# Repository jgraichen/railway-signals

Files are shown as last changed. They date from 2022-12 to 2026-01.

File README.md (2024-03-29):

# German model railway signals

<em lang="en">This repository contains 3d models, parts, and electronic components and boards to build german railway signals for H0 model railroading.</em>

## Signalkomponenten

- [Masten, Körbe, Zubehör](freecad/KS/Masten/README.md)
- [KS-Signalschirme](freecad/KS/Signalschirme/README.md)
  - [PCB für Hauptsignale](kicad/Hauptsignal/README.md)
  - [PCB für Mehrabschnittssignale](kicad/Mehrabschnittssignal/README.md)
  - [PCB für Vorsignale](kicad/Vorsignal/README.md)
- [Zusatzsignale](freecad/KS/Zusatzsignale/README.md)
  - [PCB für Zusatzsignale](kicad/Zusatzsignal/README.md)

## Zubehör

### Signal-Treiberplatinen

- [Adapterplatine für MGP Signaldekoder](kicad/extra/ws2811-adapter/README.md)
- [LED Treiberboard für ein wechselbares Lichtsperrsignal](kicad/extra/ws2811-driver-6ls/README.md)
- [LED Treiberboard für zwei wechselbare Lichtsperrsignale](kicad/extra/ws2811-driver-9ls/README.md)
- [12 LED Treiberboard (1 Signal)](kicad/extra/ws2811-driver-12/README.md)
- [24 LED Treiberboard (2 Signale)](kicad/extra/ws2811-driver-24/README.md)
- [Wattenscheider Schacht für LED Treiberboards](freecad/watti-signal-mount/README.md)

## License

See individual components. Otherwise, all components and parts are licensed under a [Creative Commons Attribution-ShareAlike 4.0 International License](http://creativecommons.org/licenses/by-sa/4.0/).

(http://creativecommons.org/licenses/by-sa/4.0/)

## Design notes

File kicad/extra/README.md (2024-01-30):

# Extra components

## WS2811 Adapter Board

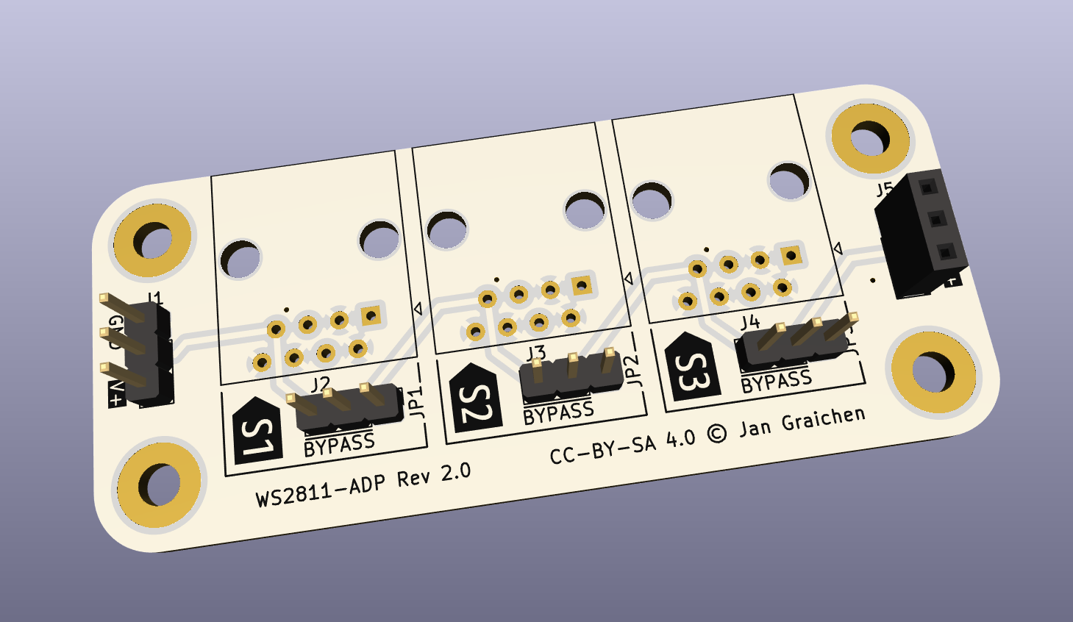
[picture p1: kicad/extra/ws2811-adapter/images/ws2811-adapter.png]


An adapter boards to connect MGP signal decoders with driver boards via RJ45 cables, for longer distances and easier cabling.

Supports bypassing ports and looping back the digital signal to organize and optimize LED ordering. See the [board README](ws2811-adapter/README.md) for more details.

## WS2811 Driver 12 (1 Signal)

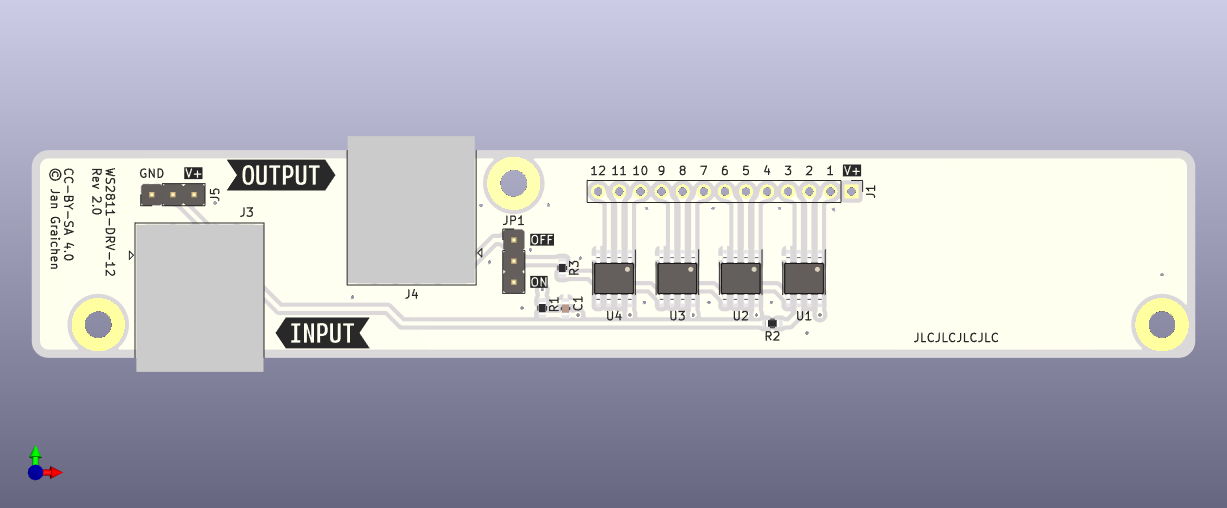
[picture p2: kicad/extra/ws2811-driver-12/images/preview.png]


[LED driver board providing 12 LEDs](ws2811-driver-12/), intended for up to one fully equipped German KS signal. Can be mounted in a [Wattenscheider Schacht](../../freecad/watti-signal-mount/).

## WS2811 Driver 24 (2 Signals)

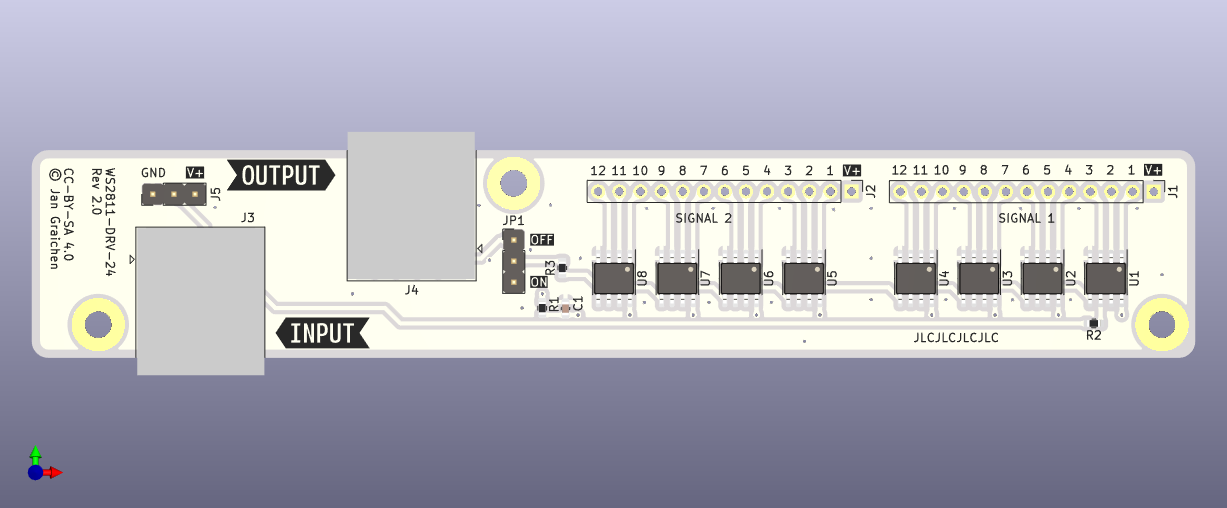
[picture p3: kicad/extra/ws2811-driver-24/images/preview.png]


A [24 LED driver board](ws2811-driver-24/) for up to two fully equipped German KS signal, usually mounted on a signal gantry. Can be mounted in a [Wattenscheider Schacht](../../freecad/watti-signal-mount/).

## WS2811 Driver 6LS (1 LS)

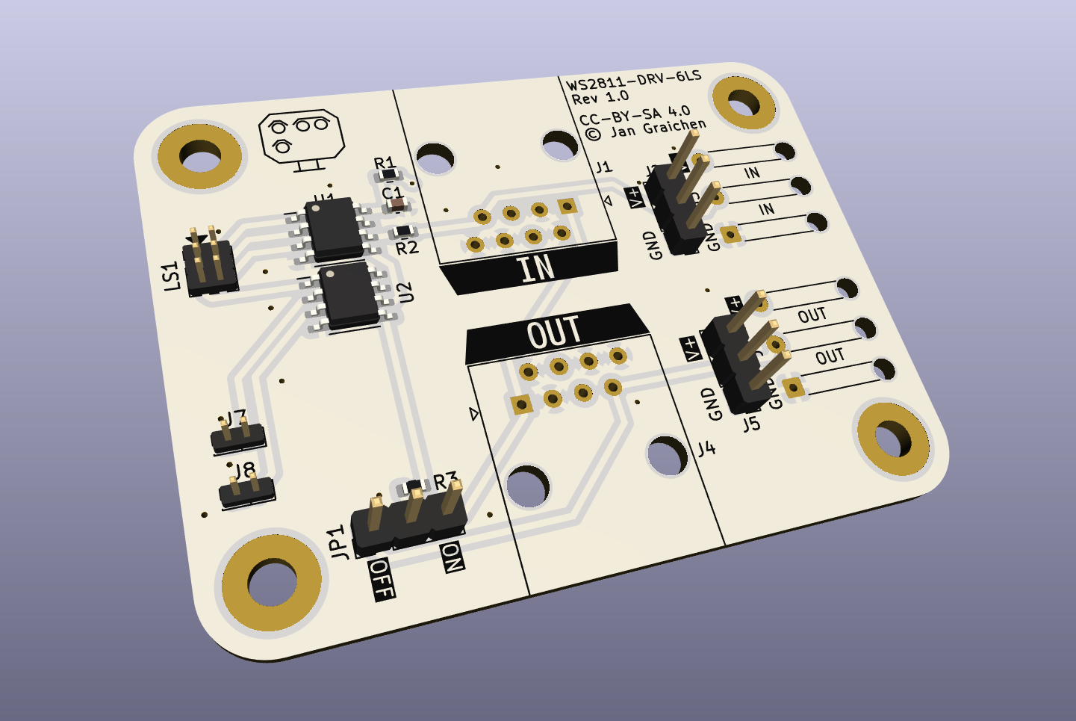
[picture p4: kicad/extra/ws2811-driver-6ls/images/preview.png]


This [driver board](ws2811-driver-6ls/) offers one tiny 2x3p 1 mm pitch connector for light shunting signals. The board can be mounted below the track, with the signal being mounted and connected through a 5 mm brass pole.

## WS2811 Driver 9LS (2 LS)

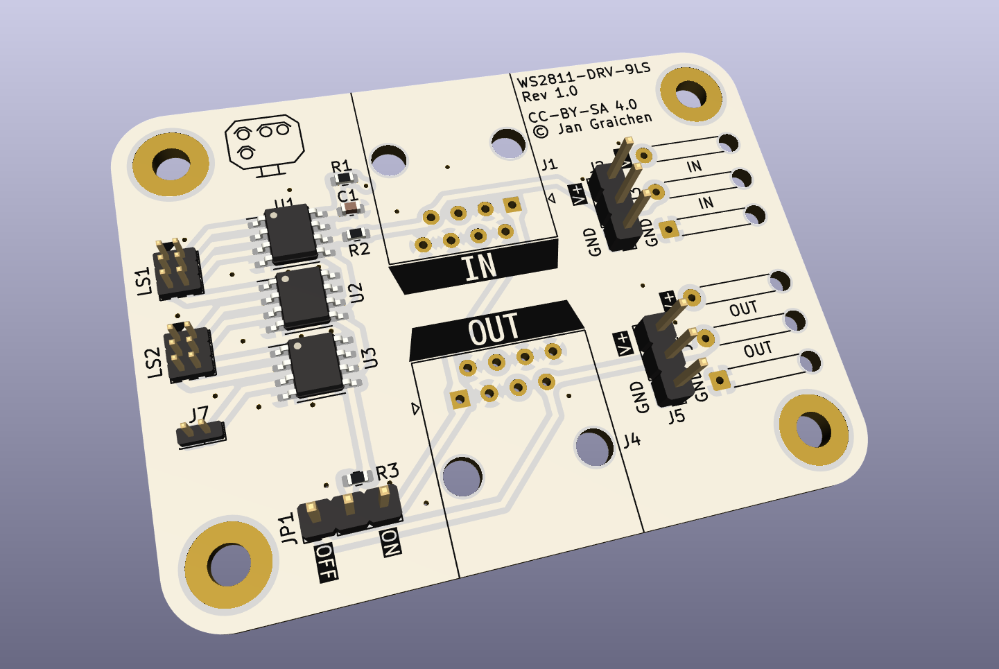
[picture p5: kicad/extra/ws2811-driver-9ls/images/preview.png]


This [driver board](ws2811-driver-9ls/) offers two tiny 2x3p 1 mm pitch connectors for light shunting signals. The board can be mounted below the track, with the signal being mounted and connected through a 5 mm brass pole.

## License

See individual components. Otherwise, all components and parts are licensed under a [Creative Commons Attribution-ShareAlike 4.0 International License](http://creativecommons.org/licenses/by-sa/4.0/).

(http://creativecommons.org/licenses/by-sa/4.0/)

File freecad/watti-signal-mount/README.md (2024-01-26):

# Wattenscheider signal mounts

With M3 screw mounts for [WS8211 LED driver boards](../../kicad/extra/).

## With latch

Signal mount has a 1 mm latch on top to stop the module from falling through.

<table>
  <tbody>
    <tr>
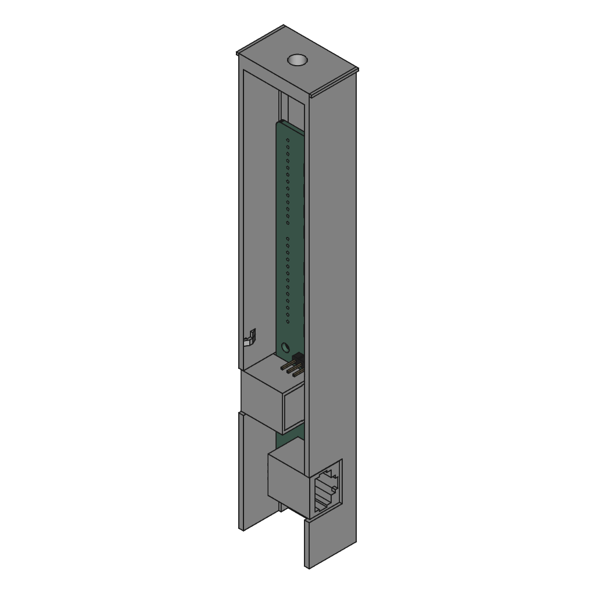
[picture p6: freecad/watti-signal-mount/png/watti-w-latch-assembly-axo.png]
      <td width="50%"></td>
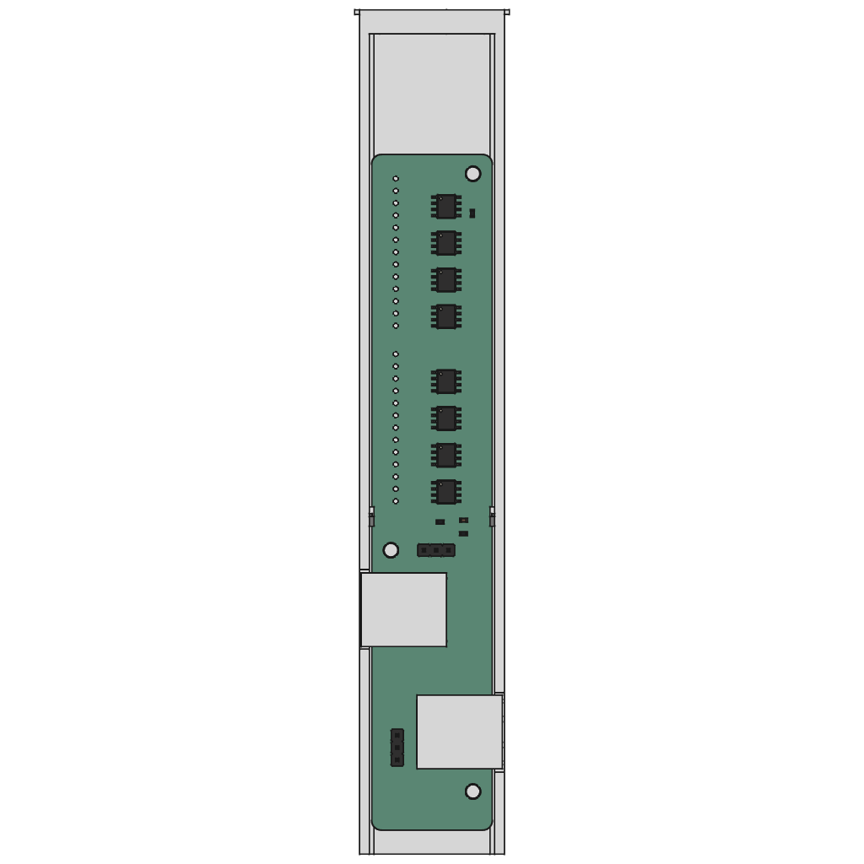
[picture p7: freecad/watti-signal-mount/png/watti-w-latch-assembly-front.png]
      <td width="50%"></td>
    </tr>
  </tbody>
</table>

* [STL model file](export/watti-w-latch-assembly.stl)
* [STEP model file](export/watti-w-latch-assembly.step)

## Without latch

<table>
  <tbody>
    <tr>
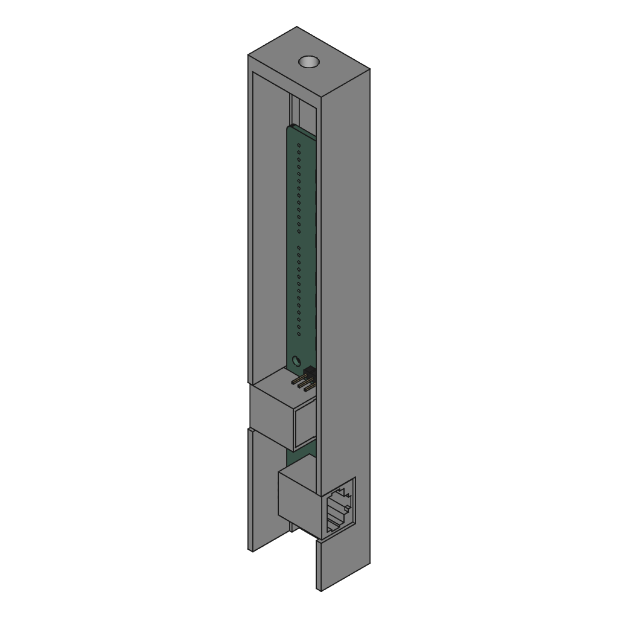
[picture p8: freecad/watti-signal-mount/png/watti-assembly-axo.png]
      <td width="50%"></td>
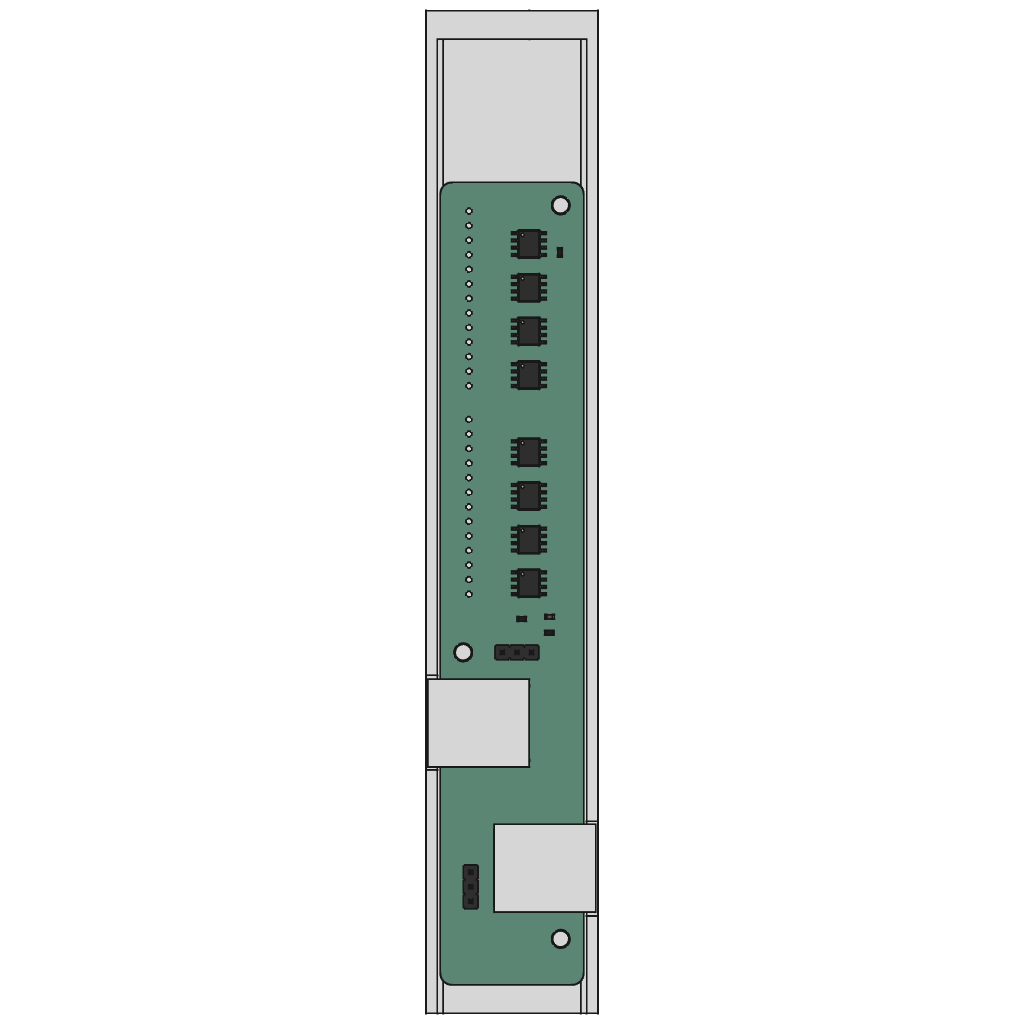
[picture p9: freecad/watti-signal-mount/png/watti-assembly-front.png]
      <td width="50%"></td>
    </tr>
  </tbody>
</table>

* [STL model file](export/watti-assembly.stl)
* [STEP model file](export/watti-assembly.step)

## License

This work is licensed under a
[Creative Commons Attribution-ShareAlike 4.0 International License](http://creativecommons.org/licenses/by-sa/4.0/).

(http://creativecommons.org/licenses/by-sa/4.0/)

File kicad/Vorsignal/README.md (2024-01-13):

# Vorsignal

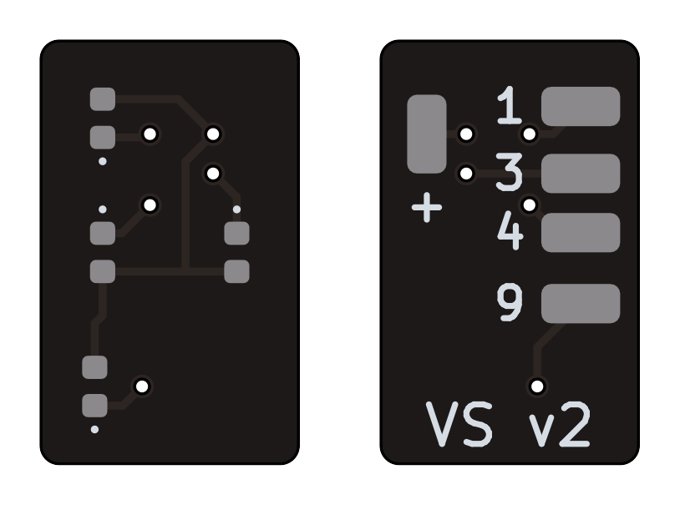
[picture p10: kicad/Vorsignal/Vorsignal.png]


Geeignet für KS-Vorsignale.

## Anschlussbelegung

| Schema | Pin-Belegung |
| --- | --- |
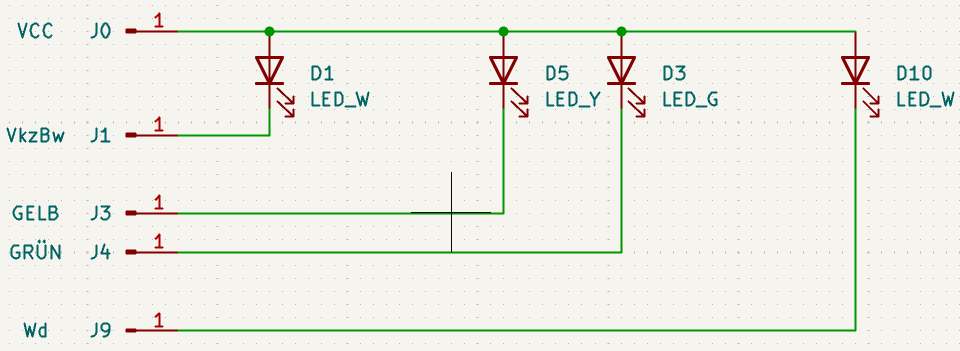
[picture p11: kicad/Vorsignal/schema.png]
Schema
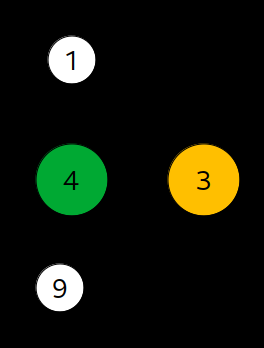
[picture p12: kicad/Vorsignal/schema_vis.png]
Pin-Belegung
|  |  |

| Referenz | Pin | LED | Funktion |
| --- | --- | --- | --- |
| J0 | + | | Stromversorgung (+) |
| J1 | 1 | Kaltweiß | Verkürzter Bremswegabstand |
| J3 | 3 | Gelb | Ks2 (Halt erwarten) |
| J4 | 4 | Grün | Ks1 (Fahrt erwarten) |
| J9 | 9 | Kaltweiß | Wiederholer |

## License

This work is licensed under a
[Creative Commons Attribution-ShareAlike 4.0 International License](http://creativecommons.org/licenses/by-sa/4.0/).

(http://creativecommons.org/licenses/by-sa/4.0/)

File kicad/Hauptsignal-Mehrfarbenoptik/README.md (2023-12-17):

# Hauptsignal mit mehrfarbiger Optik MSOv1

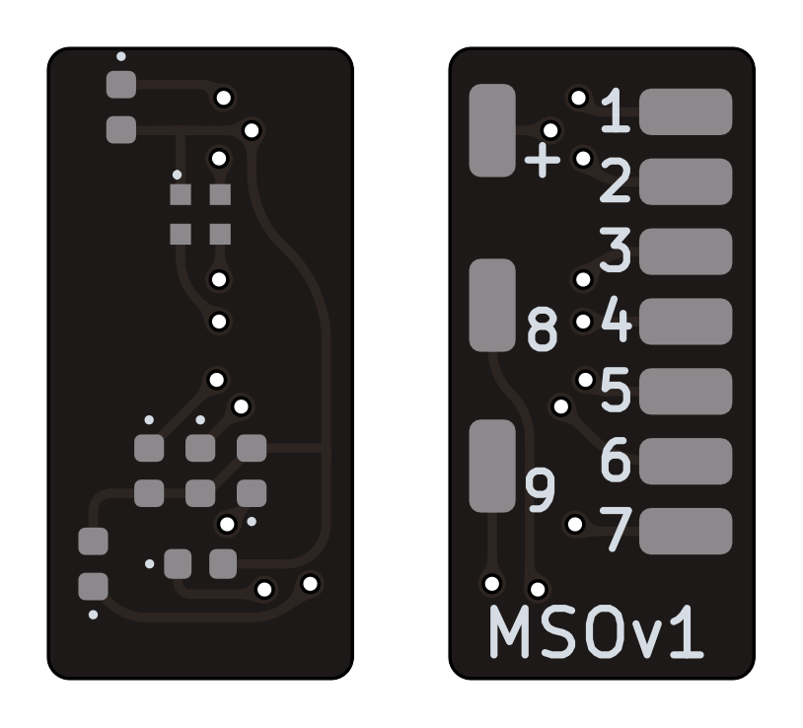
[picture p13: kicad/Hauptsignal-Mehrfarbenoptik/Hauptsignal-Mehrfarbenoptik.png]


Geeignet für KS-Hauptsignale und Mehrabschnitssignale mit mehrfarbiger Optik über eine ARGB-LED.

Pin 1 muss die gemeinsame Anode der RGB LED sein, die anderen Pins können je nach Bedarf Rot, Grün, oder Blau sein. Das ermöglicht auch den Einsatz auch von zum Beispiel ARGB und ARBG LEDs.

## Anschlussbelegung

| Schema | Pin-Belegung |
| --- | --- |
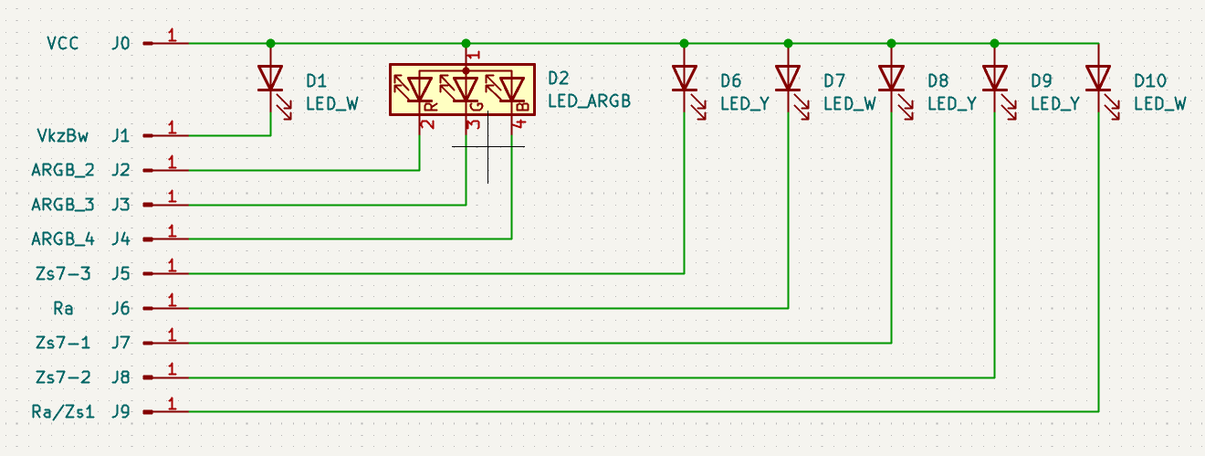
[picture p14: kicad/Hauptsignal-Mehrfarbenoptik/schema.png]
Schema
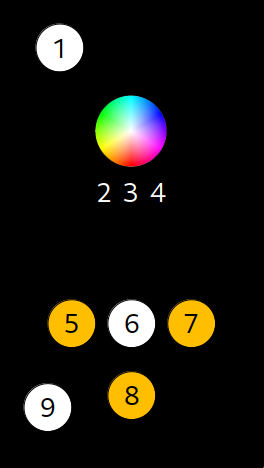
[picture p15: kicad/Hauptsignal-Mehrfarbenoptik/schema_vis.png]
Pin-Belegung
|  |  |

| Referenz | Pin | LED | Funktion |
| --- | --- | --- | --- |
| J0 | + | | Stromversorgung (+) |
| J1 | 1 | Kaltweiß | Zusatzlicht (oben) |
| J2 | 2 | ARGB_2 | RGB Led Pin 2 |
| J3 | 3 | ARGB_3 | RGB Led Pin 3 |
| J4 | 4 | ARGB_4 | RGB Led Pin 4 |
| J5 | 5 | Gelb | Zs7 |
| J6 | 6 | Kaltweiß | Sh1/Ra12 |
| J7 | 7 | Gelb | Zs7 |
| J8 | 8 | Gelb | Zs7 |
| J9 | 9 | Kaltweiß | Sh1/Ra12/Zs1/Zusatzlicht (unten) |

## License

This work is licensed under a
[Creative Commons Attribution-ShareAlike 4.0 International License](http://creativecommons.org/licenses/by-sa/4.0/).

(http://creativecommons.org/licenses/by-sa/4.0/)

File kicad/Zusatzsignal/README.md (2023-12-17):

# Zusatzsignal ZSv2

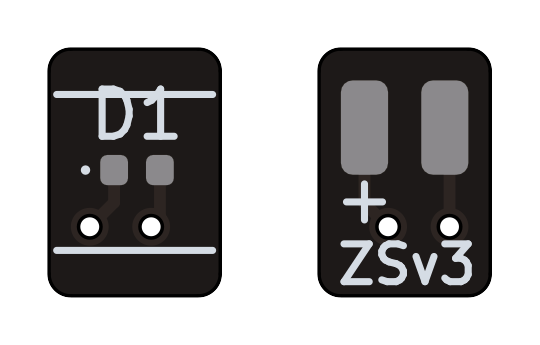
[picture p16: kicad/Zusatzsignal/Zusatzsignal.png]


Geeignet für Zusatzsignale über oder unter dem Signalschirm.

## Anschlussbelegung

| Referenz | Pin | LED | Funktion |
| --- | --- | --- | --- |
| | + | | Stromversorgung (+) |
| | | | Masse |

## License

This work is licensed under a
[Creative Commons Attribution-ShareAlike 4.0 International License](http://creativecommons.org/licenses/by-sa/4.0/).

(http://creativecommons.org/licenses/by-sa/4.0/)

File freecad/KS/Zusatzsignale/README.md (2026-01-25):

# Zusatzsignale

## Lichtsignale

<table width="100%">
  <thead>
    <tr>
      <th colspan="2">Vorschau</th>
      <th>Anmerkungen</th>
    </tr>
  </thead>
  <tbody>
    <tr>
      <td width="200" align="center">
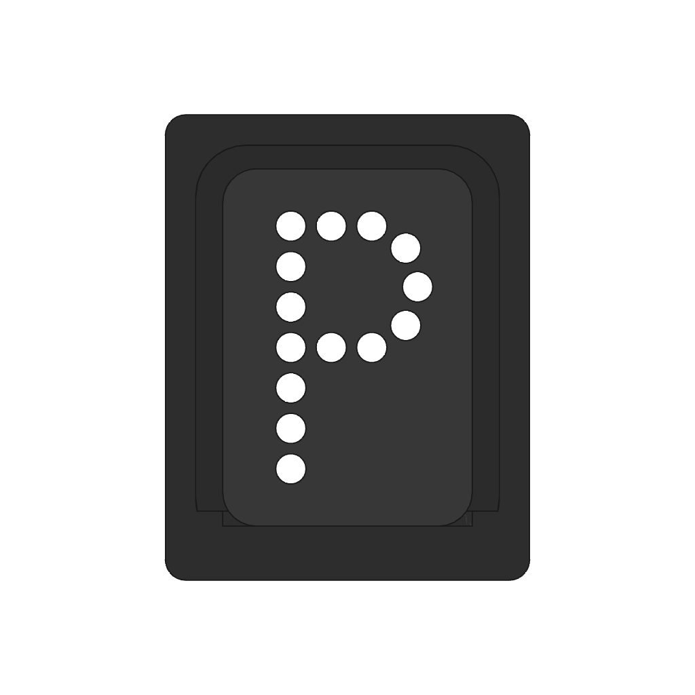
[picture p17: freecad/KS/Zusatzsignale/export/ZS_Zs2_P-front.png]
        
        <br>
        <a href="export/ZS_Zs2_P.step">STEP</a> · <a href="export/ZS_Zs2_P.stl">STL</a>
      </td>
      <td width="200" align="center">
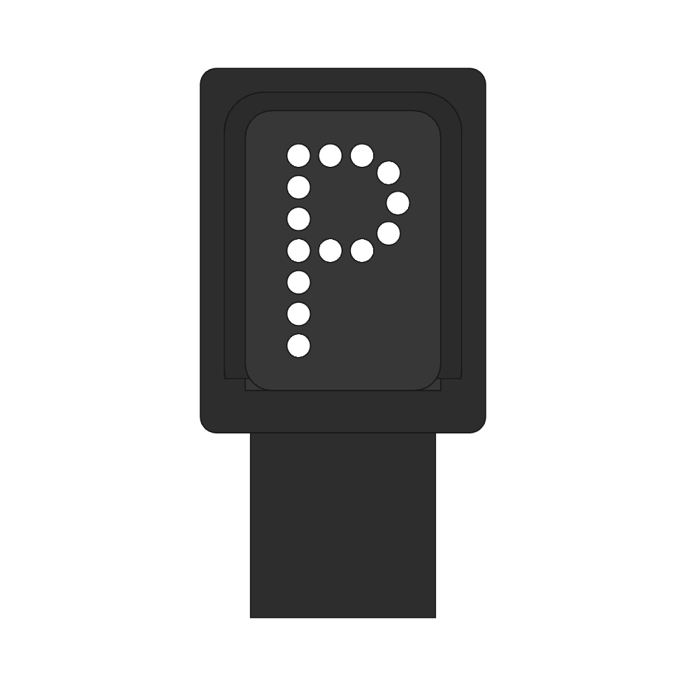
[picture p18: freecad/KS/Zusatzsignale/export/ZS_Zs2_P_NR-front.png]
        
        <br>
        <a href="export/ZS_Zs2_P_NR.step">STEP</a> · <a href="export/ZS_Zs2_P_NR.stl">STL</a>
      </td>
      <td>
        <p>
          <em>ZS_Zs2_P</em>
        </p>
        <ul>
          <li>Richtung "P"</li>
        </ul>
      </td>
    </tr>
    <tr>
      <td width="200" align="center">
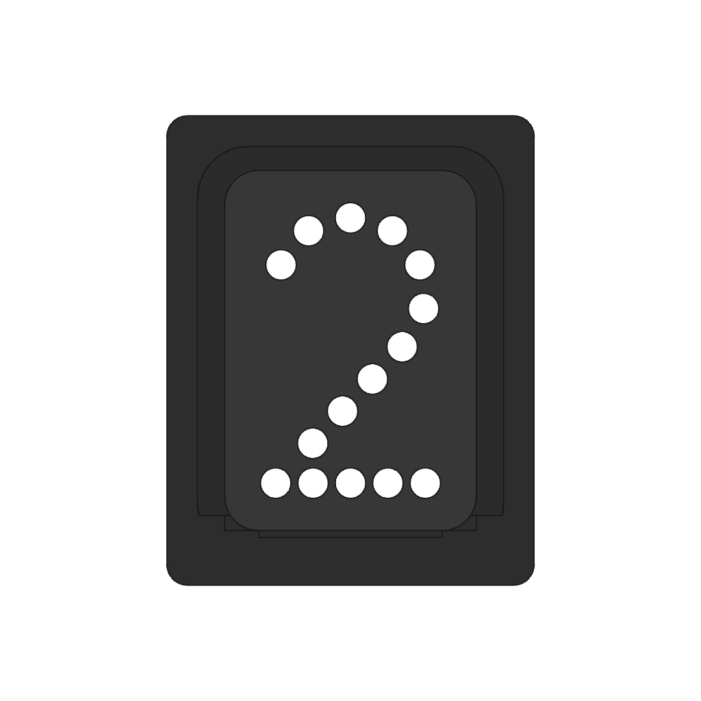
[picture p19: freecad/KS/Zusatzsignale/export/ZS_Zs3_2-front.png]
        
        <br>
        <a href="export/ZS_Zs3_2.step">STEP</a> · <a href="export/ZS_Zs3_2.stl">STL</a>
      </td>
      <td width="200" align="center">
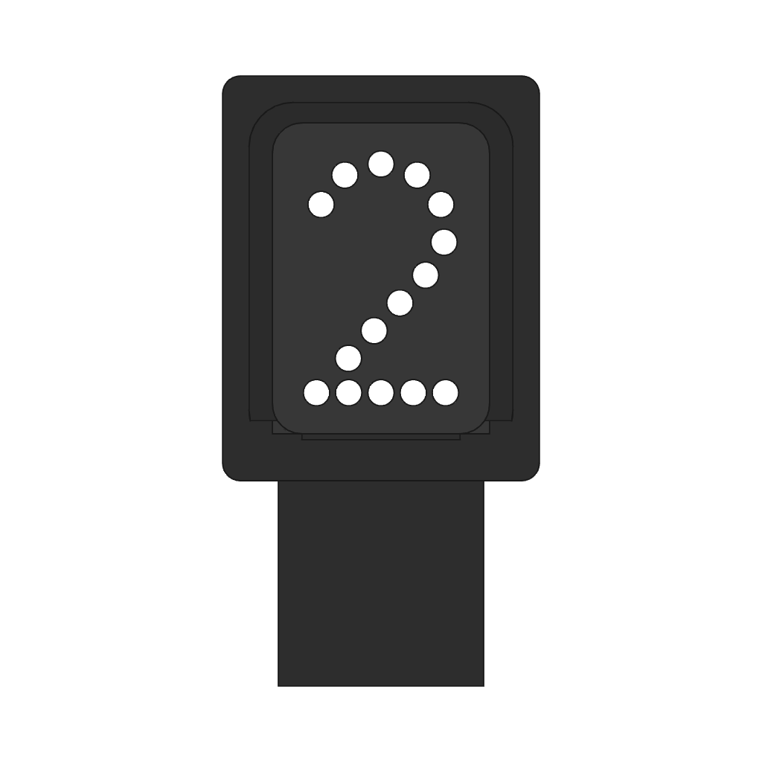
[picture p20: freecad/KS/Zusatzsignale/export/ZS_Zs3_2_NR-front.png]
        
        <br>
        <a href="export/ZS_Zs3_2_NR.step">STEP</a> · <a href="export/ZS_Zs3_2_NR.stl">STL</a>
      </td>
      <td>
        <p>
          <em>ZS_Zs3_2</em>
        </p>
        <ul>
          <li>20 km/h</li>
        </ul>
      </td>
    </tr>
    <tr>
      <td width="200" align="center">
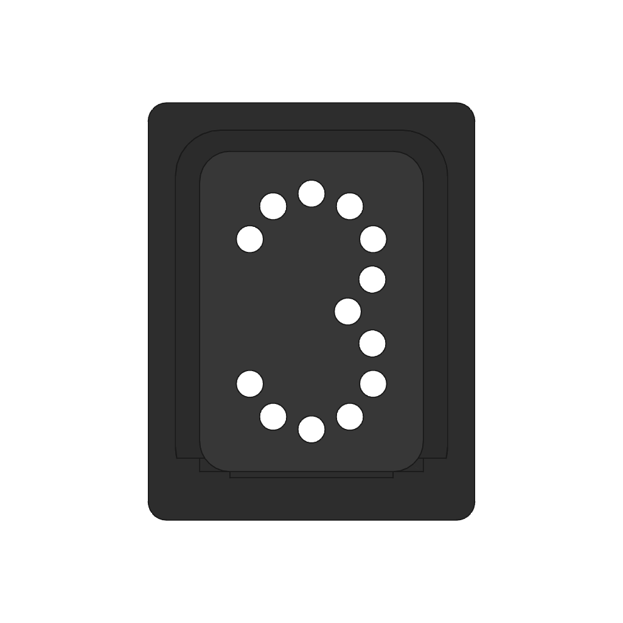
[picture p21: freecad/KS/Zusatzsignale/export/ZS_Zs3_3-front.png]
        
        <br>
        <a href="export/ZS_Zs3_3.step">STEP</a> · <a href="export/ZS_Zs3_3.stl">STL</a>
      </td>
      <td width="200" align="center">
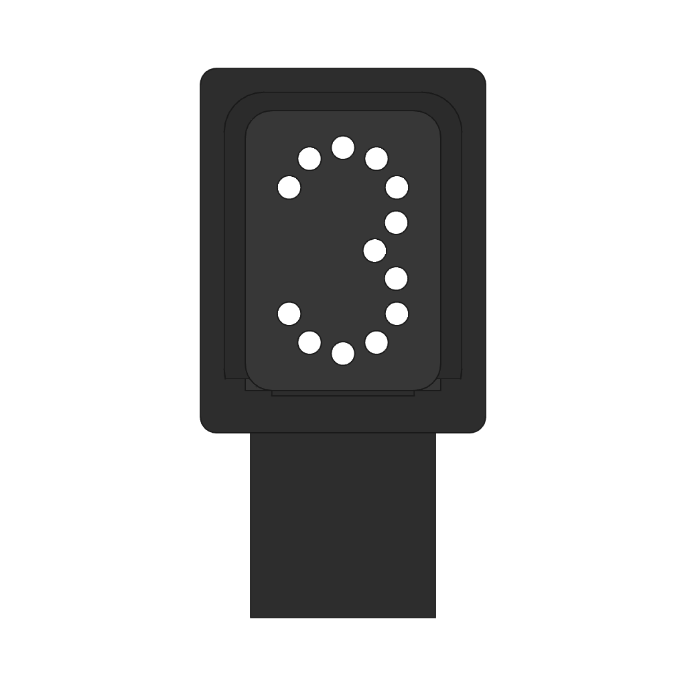
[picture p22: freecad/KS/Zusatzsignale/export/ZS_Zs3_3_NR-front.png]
        
        <br>
        <a href="export/ZS_Zs3_3_NR.step">STEP</a> · <a href="export/ZS_Zs3_3_NR.stl">STL</a>
      </td>
      <td>
        <p>
          <em>ZS_Zs3_3</em>
        </p>
        <ul>
          <li>30 km/h</li>
        </ul>
      </td>
    </tr>
    <tr>
      <td width="200" align="center">
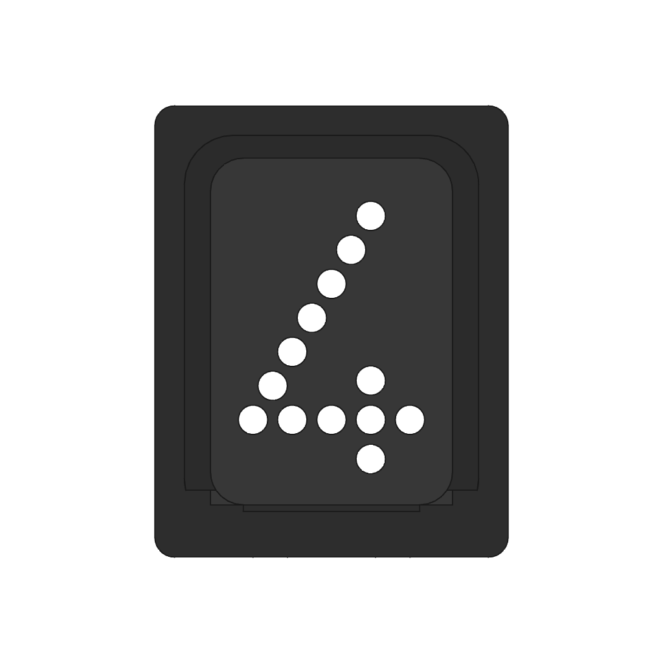
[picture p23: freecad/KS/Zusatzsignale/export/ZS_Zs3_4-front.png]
        
        <br>
        <a href="export/ZS_Zs3_4.step">STEP</a> · <a href="export/ZS_Zs3_4.stl">STL</a>
      </td>
      <td width="200" align="center">
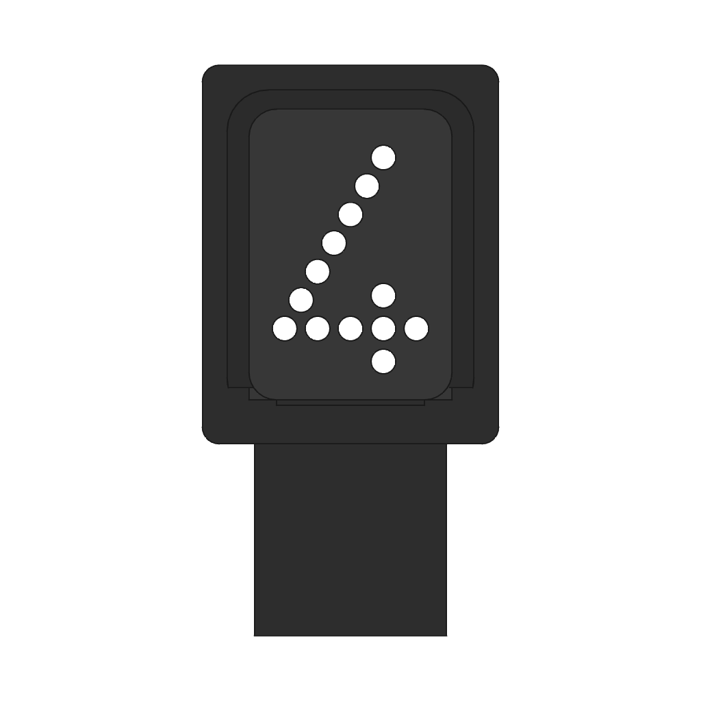
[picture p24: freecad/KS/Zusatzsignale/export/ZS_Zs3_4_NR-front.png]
        
        <br>
        <a href="export/ZS_Zs3_4_NR.step">STEP</a> · <a href="export/ZS_Zs3_4_NR.stl">STL</a>
      </td>
      <td>
        <p>
          <em>ZS_Zs3_4</em>
        </p>
        <ul>
          <li>40 km/h</li>
        </ul>
      </td>
    </tr>
    <tr>
      <td width="200" align="center"></td>
      <td width="200" align="center">
        
        <br>
        <a href="export/ZS_Zs6_NR.step">STEP</a> · <a href="export/ZS_Zs6_NR.stl">STL</a>
      </td>
      <td>
        <p>
          <em>ZS_Zs6</em>
        </p>
        <ul>
          <li>Gegengleisanzeiger</li>
        </ul>
      </td>
    </tr>
  </tbody>
</table>

## Feste Signale

<table width="100%">
  <thead>
    <tr>
      <th colspan="1">Vorschau</th>
      <th>Anmerkungen</th>
    </tr>
  </thead>
  <tbody>
    <tr>
      <td width="410" align="center">
        
        
        <br>
        <a href="export/ZS_Zs3_Fest.step">STEP</a> · <a href="export/ZS_Zs3_Fest.stl">STL</a>
      </td>
      <td>
        <p>
          <em>ZS_Zs3_Fest</em>
        </p>
        <ul>
          <li>Zs3</li>
        </ul>
      </td>
    </tr>
    <tr>
      <td width="410" align="center">
        
        
        <br>
        <a href="export/ZS_Zs3v_Fest.step">STEP</a> · <a href="export/ZS_Zs3v_Fest.stl">STL</a>
      </td>
      <td>
        <p>
          <em>ZS_Zs3v_Fest</em>
        </p>
        <ul>
          <li>Zs3v</li>
        </ul>
      </td>
    </tr>
    <tr>
      <td width="410" align="center">
        
        
        <br>
        <a href="export/ZS_Zs6_Fest_NR.step">STEP</a> · <a href="export/ZS_Zs6_Fest_NR.stl">STL</a>
      </td>
      <td>
        <p>
          <em>ZS_Zs6_Fest_NR</em>
        </p>
        <ul>
          <li>Gegengleisanzeiger</li>
        </ul>
      </td>
    </tr>
  </tbody>
</table>

## Zubehör

<table width="100%">
  <thead>
    <tr>
      <th colspan="1">Vorschau</th>
      <th>Anmerkungen</th>
    </tr>
  </thead>
  <tbody>
    <tr>
      <td width="410" align="center">
        
        
        <br>
        <a href="export/ZS_Halterung.step">STEP</a> · <a href="export/ZS_Halterung.stl">STL</a>
      </td>
      <td>
        <p>
          <em>ZS_Halterung</em>
        </p>
        <ul>
          <li>Halterung für Zusatzsignale am Mast</li>
        </ul>
      </td>
    </tr>
    <tr>
      <td width="410" align="center">
        
        
        <br>
        <a href="export/ZS_Diffusor_96um.step">STEP</a> · <a href="export/ZS_Diffusor_96um.stl">STL</a>
      </td>
      <td>
        <p>
          <em>ZS_Diffusor_96um</em>
        </p>
        <ul>
          <li>Diffusor für Lichtzusatzsignale</li>
          <li>96µm (empfohlen)</li>
        </ul>
      </td>
    </tr>
    <tr>
      <td width="410" align="center">
        
        
        <br>
        <a href="export/ZS_Diffusor_72um.step">STEP</a> · <a href="export/ZS_Diffusor_72um.stl">STL</a>
      </td>
      <td>
        <p>
          <em>ZS_Diffusor_72um</em>
        </p>
        <ul>
          <li>Diffusor für Lichtzusatzsignale</li>
          <li>72µm</li>
        </ul>
      </td>
    </tr>
    <tr>
      <td width="410" align="center">
        
        
        <br>
        <a href="export/ZS_Diffusor_48um.step">STEP</a> · <a href="export/ZS_Diffusor_48um.stl">STL</a>
      </td>
      <td>
        <p>
          <em>ZS_Diffusor_48um</em>
        </p>
        <ul>
          <li>Diffusor für Lichtzusatzsignale</li>
          <li>48µm</li>
        </ul>
      </td>
    </tr>
  </tbody>
</table>

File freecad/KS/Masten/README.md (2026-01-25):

# Masten

## Gittermasten

<table width="100%">
  <thead>
    <tr>
      <th colspan="1">Vorschau</th>
      <th>Anmerkungen</th>
    </tr>
  </thead>
  <tbody>
    <tr>
      <td width="410" align="center">
        
        
        <br>
        <a href="export/Gittermast_60_1ZS.step">STEP</a> · <a href="export/Gittermast_60_1ZS.stl">STL</a>
      </td>
      <td>
        <p>
          <em>Gittermast_60_1ZS</em>
        </p>
        <ul>
          <li>Ein Zusatzsignal</li>
        </ul>
      </td>
    </tr>
    <tr>
      <td width="410" align="center">
        
        
        <br>
        <a href="export/Gittermast_60_2ZS.step">STEP</a> · <a href="export/Gittermast_60_2ZS.stl">STL</a>
      </td>
      <td>
        <p>
          <em>Gittermast_60_2ZS</em>
        </p>
        <ul>
          <li>Zwei Zusatzsignale</li>
        </ul>
      </td>
    </tr>
  </tbody>
</table>

## Auslegermasten

<table width="100%">
  <thead>
    <tr>
      <th colspan="1">Vorschau</th>
      <th>Anmerkungen</th>
    </tr>
  </thead>
  <tbody>
    <tr>
      <td width="410" align="center">
        
        
        <br>
        <a href="export/Auslegermast_48_40R_1ZS.step">STEP</a> · <a href="export/Auslegermast_48_40R_1ZS.stl">STL</a>
      </td>
      <td>
        <p>
          <em>Auslegermast_48_40R_1ZS</em>
        </p>
        <ul>
          <li>40er Ausleger</li>
          <li>Rechts vom Gleis</li>
        </ul>
      </td>
    </tr>
    <tr>
      <td width="410" align="center">
        
        
        <br>
        <a href="export/Auslegermast_48_40L_1ZS.step">STEP</a> · <a href="export/Auslegermast_48_40L_1ZS.stl">STL</a>
      </td>
      <td>
        <p>
          <em>Auslegermast_48_40L_1ZS</em>
        </p>
        <ul>
          <li>40er Ausleger</li>
          <li>Links vom Gleis</li>
        </ul>
      </td>
    </tr>
  </tbody>
</table>

## Mastschilder

<table width="100%">
  <thead>
    <tr>
      <th colspan="1">Vorschau</th>
      <th>Anmerkungen</th>
    </tr>
  </thead>
  <tbody>
    <tr>
      <td width="410" align="center">
        
        
        <br>
        <a href="export/Mastschild_16_MS.step">STEP</a> · <a href="export/Mastschild_16_MS.stl">STL</a>
      </td>
      <td>
        <p>
          <em>Mastschild_16_MS</em>
        </p>
      </td>
    </tr>
    <tr>
      <td width="410" align="center">
        
        
        <br>
        <a href="export/Mastschild_16_VS.step">STEP</a> · <a href="export/Mastschild_16_VS.stl">STL</a>
      </td>
      <td>
        <p>
          <em>Mastschild_16_VS</em>
        </p>
      </td>
    </tr>
    <tr>
      <td width="410" align="center">
        
        
        <br>
        <a href="export/Mastschild_26_MS.step">STEP</a> · <a href="export/Mastschild_26_MS.stl">STL</a>
      </td>
      <td>
        <p>
          <em>Mastschild_26_MS</em>
        </p>
      </td>
    </tr>
    <tr>
      <td width="410" align="center">
        
        
        <br>
        <a href="export/Mastschild_26_VS.step">STEP</a> · <a href="export/Mastschild_26_VS.stl">STL</a>
      </td>
      <td>
        <p>
          <em>Mastschild_26_VS</em>
        </p>
      </td>
    </tr>
  </tbody>
</table>

## Zubehör

<table width="100%">
  <thead>
    <tr>
      <th colspan="1">Vorschau</th>
      <th>Anmerkungen</th>
    </tr>
  </thead>
  <tbody>
    <tr>
      <td width="410" align="center">
        
        
        <br>
        <a href="export/Mast_Korb_1.step">STEP</a> · <a href="export/Mast_Korb_1.stl">STL</a>
      </td>
      <td>
        <p>
          <em>Mast_Korb_1</em>
        </p>
      </td>
    </tr>
    <tr>
      <td width="410" align="center">
        
        
        <br>
        <a href="export/Mast_Auslegerkorb_40.step">STEP</a> · <a href="export/Mast_Auslegerkorb_40.stl">STL</a>
      </td>
      <td>
        <p>
          <em>Mast_Auslegerkorb_40</em>
        </p>
        <ul>
          <li>40er Auslegerkorb</li>
        </ul>
      </td>
    </tr>
    <tr>
      <td width="410" align="center">
        
        
        <br>
        <a href="export/Mast_Auslegerkorb_80.step">STEP</a> · <a href="export/Mast_Auslegerkorb_80.stl">STL</a>
      </td>
      <td>
        <p>
          <em>Mast_Auslegerkorb_80</em>
        </p>
        <ul>
          <li>80er Auslegerkorb</li>
        </ul>
      </td>
    </tr>
    <tr>
      <td width="410" align="center">
        
        
        <br>
        <a href="export/Leiter_16.step">STEP</a> · <a href="export/Leiter_16.stl">STL</a>
      </td>
      <td>
        <p>
          <em>Leiter_16</em>
        </p>
      </td>
    </tr>
    <tr>
      <td width="410" align="center">
        
        
        <br>
        <a href="export/Leiter_16_0504.step">STEP</a> · <a href="export/Leiter_16_0504.stl">STL</a>
      </td>
      <td>
        <p>
          <em>Leiter_16_0504</em>
        </p>
      </td>
    </tr>
    <tr>
      <td width="410" align="center">
        
        
        <br>
        <a href="export/Leiter_26.step">STEP</a> · <a href="export/Leiter_26.stl">STL</a>
      </td>
      <td>
        <p>
          <em>Leiter_26</em>
        </p>
      </td>
    </tr>
    <tr>
      <td width="410" align="center">
        
        
        <br>
        <a href="export/Leiter_26_0504.step">STEP</a> · <a href="export/Leiter_26_0504.stl">STL</a>
      </td>
      <td>
        <p>
          <em>Leiter_26_0504</em>
        </p>
      </td>
    </tr>
    <tr>
      <td width="410" align="center">
        
        
        <br>
        <a href="export/Technik_1.step">STEP</a> · <a href="export/Technik_1.stl">STL</a>
      </td>
      <td>
        <p>
          <em>Technik_1</em>
        </p>
      </td>
    </tr>
    <tr>
      <td width="410" align="center">
        
        
        <br>
        <a href="export/Sockel.step">STEP</a> · <a href="export/Sockel.stl">STL</a>
      </td>
      <td>
        <p>
          <em>Sockel</em>
        </p>
      </td>
    </tr>
  </tbody>
</table>

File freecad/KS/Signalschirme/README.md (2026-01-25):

# Signalschirme

## Mehrabschnitssignale

<table width="100%">
  <thead>
    <tr>
      <th colspan="2">Vorschau</th>
      <th>Anmerkungen</th>
    </tr>
  </thead>
  <tbody>
    <tr>
      <td width="200" align="center"></td>
      <td width="200" align="center">
        
        <br>
        <a href="export/MS__B.step">STEP</a> · <a href="export/MS__B.stl">STL</a>
      </td>
      <td>
        <p>
          <em>MS</em>
        </p>
      </td>
    </tr>
    <tr>
      <td width="200" align="center"></td>
      <td width="200" align="center">
        
        <br>
        <a href="export/MS_vBw__B.step">STEP</a> · <a href="export/MS_vBw__B.stl">STL</a>
      </td>
      <td>
        <p>
          <em>MS_vBw</em>
        </p>
        <ul>
          <li>Kennlicht</li>
          <li>Verkürzter Bremswegabstand</li>
        </ul>
      </td>
    </tr>
    <tr>
      <td width="200" align="center">
        
        <br>
        <a href="export/MS_Sh1__A.step">STEP</a> · <a href="export/MS_Sh1__A.stl">STL</a>
      </td>
      <td width="200" align="center">
        
        <br>
        <a href="export/MS_Sh1__B.step">STEP</a> · <a href="export/MS_Sh1__B.stl">STL</a>
      </td>
      <td>
        <p>
          <em>MS_Sh1</em>
        </p>
        <ul>
          <li>Rangiersignal</li>
          <li>Ersatzsignal</li>
        </ul>
      </td>
    </tr>
    <tr>
      <td width="200" align="center">
        
        <br>
        <a href="export/MS_Sh1_vBw__A.step">STEP</a> · <a href="export/MS_Sh1_vBw__A.stl">STL</a>
      </td>
      <td width="200" align="center">
        
        <br>
        <a href="export/MS_Sh1_vBw__B.step">STEP</a> · <a href="export/MS_Sh1_vBw__B.stl">STL</a>
      </td>
      <td>
        <p>
          <em>MS_Sh1_vBw</em>
        </p>
        <ul>
          <li>Kennlicht</li>
          <li>Rangiersignal</li>
          <li>Ersatzsignal</li>
          <li>Verkürzter Bremswegabstand</li>
        </ul>
      </td>
    </tr>
    <tr>
      <td width="200" align="center">
        
        <br>
        <a href="export/MS_Zs1__A.step">STEP</a> · <a href="export/MS_Zs1__A.stl">STL</a>
      </td>
      <td width="200" align="center">
        
        <br>
        <a href="export/MS_Zs1__B.step">STEP</a> · <a href="export/MS_Zs1__B.stl">STL</a>
      </td>
      <td>
        <p>
          <em>MS_Zs1</em>
        </p>
        <ul>
          <li>Ersatzsignal</li>
        </ul>
      </td>
    </tr>
    <tr>
      <td width="200" align="center">
        
        <br>
        <a href="export/MS_Zs1_vBw__A.step">STEP</a> · <a href="export/MS_Zs1_vBw__A.stl">STL</a>
      </td>
      <td width="200" align="center">
        
        <br>
        <a href="export/MS_Zs1_vBw__B.step">STEP</a> · <a href="export/MS_Zs1_vBw__B.stl">STL</a>
      </td>
      <td>
        <p>
          <em>MS_Zs1_vBw</em>
        </p>
        <ul>
          <li>Kennlicht</li>
          <li>Ersatzsignal</li>
          <li>Verkürzter Bremswegabstand</li>
        </ul>
      </td>
    </tr>
    <tr>
      <td width="200" align="center">
        
        <br>
        <a href="export/MS_Zs7__A.step">STEP</a> · <a href="export/MS_Zs7__A.stl">STL</a>
      </td>
      <td width="200" align="center">
        
        <br>
        <a href="export/MS_Zs7__B.step">STEP</a> · <a href="export/MS_Zs7__B.stl">STL</a>
      </td>
      <td>
        <p>
          <em>MS_Zs7</em>
        </p>
        <ul>
          <li>Vorsichtssignal</li>
        </ul>
      </td>
    </tr>
    <tr>
      <td width="200" align="center">
        
        <br>
        <a href="export/MS_Zs7_vBw__A.step">STEP</a> · <a href="export/MS_Zs7_vBw__A.stl">STL</a>
      </td>
      <td width="200" align="center">
        
        <br>
        <a href="export/MS_Zs7_vBw__B.step">STEP</a> · <a href="export/MS_Zs7_vBw__B.stl">STL</a>
      </td>
      <td>
        <p>
          <em>MS_Zs7_vBw</em>
        </p>
        <ul>
          <li>Kennlicht</li>
          <li>Vorsichtssignal</li>
          <li>Verkürzter Bremswegabstand</li>
        </ul>
      </td>
    </tr>
    <tr>
      <td width="200" align="center"></td>
      <td width="200" align="center">
        
        <br>
        <a href="export/MS_Zs7_Sh1__B.step">STEP</a> · <a href="export/MS_Zs7_Sh1__B.stl">STL</a>
      </td>
      <td>
        <p>
          <em>MS_Zs7_Sh1</em>
        </p>
        <ul>
          <li>Kennlicht</li>
          <li>Vorsichtssignal</li>
          <li>Rangiersignal</li>
        </ul>
      </td>
    </tr>
    <tr>
      <td width="200" align="center"></td>
      <td width="200" align="center">
        
        <br>
        <a href="export/MS_Zs7_Sh1_vBw__B.step">STEP</a> · <a href="export/MS_Zs7_Sh1_vBw__B.stl">STL</a>
      </td>
      <td>
        <p>
          <em>MS_Zs7_Sh1_vBw</em>
        </p>
        <ul>
          <li>Kennlicht</li>
          <li>Vorsichtssignal</li>
          <li>Rangiersignal</li>
          <li>Verkürzter Bremswegabstand</li>
        </ul>
      </td>
    </tr>
    <tr>
      <td width="200" align="center">
        
        <br>
        <a href="export/MS_Zs7_Zs1__A.step">STEP</a> · <a href="export/MS_Zs7_Zs1__A.stl">STL</a>
      </td>
      <td width="200" align="center">
        
        <br>
        <a href="export/MS_Zs7_Zs1__B.step">STEP</a> · <a href="export/MS_Zs7_Zs1__B.stl">STL</a>
      </td>
      <td>
        <p>
          <em>MS_Zs7_Zs1</em>
        </p>
        <ul>
          <li>Vorsichtssignal</li>
          <li>Ersatzsignal (links unten)</li>
        </ul>
      </td>
    </tr>
    <tr>
      <td width="200" align="center">
        
        <br>
        <a href="export/MS_Zs7_Zs1_vBw__A.step">STEP</a> · <a href="export/MS_Zs7_Zs1_vBw__A.stl">STL</a>
      </td>
      <td width="200" align="center">
        
        <br>
        <a href="export/MS_Zs7_Zs1_vBw__B.step">STEP</a> · <a href="export/MS_Zs7_Zs1_vBw__B.stl">STL</a>
      </td>
      <td>
        <p>
          <em>MS_Zs7_Zs1_vBw</em>
        </p>
        <ul>
          <li>Kennlicht</li>
          <li>Vorsichtssignal</li>
          <li>Ersatzsignal (links unten)</li>
          <li>Verkürzter Bremswegabstand</li>
        </ul>
      </td>
    </tr>
    <tr>
      <td width="200" align="center">
        
        <br>
        <a href="export/MS_Zs7_Zs1m__A.step">STEP</a> · <a href="export/MS_Zs7_Zs1m__A.stl">STL</a>
      </td>
      <td width="200" align="center">
        
        <br>
        <a href="export/MS_Zs7_Zs1m__B.step">STEP</a> · <a href="export/MS_Zs7_Zs1m__B.stl">STL</a>
      </td>
      <td>
        <p>
          <em>MS_Zs7_Zs1m</em>
        </p>
        <ul>
          <li>Vorsichtssignal</li>
          <li>Ersatzsignal (mittig)</li>
        </ul>
      </td>
    </tr>
    <tr>
      <td width="200" align="center">
        
        <br>
        <a href="export/MS_Zs7_Zs1m_vBw__A.step">STEP</a> · <a href="export/MS_Zs7_Zs1m_vBw__A.stl">STL</a>
      </td>
      <td width="200" align="center">
        
        <br>
        <a href="export/MS_Zs7_Zs1m_vBw__B.step">STEP</a> · <a href="export/MS_Zs7_Zs1m_vBw__B.stl">STL</a>
      </td>
      <td>
        <p>
          <em>MS_Zs7_Zs1m_vBw</em>
        </p>
        <ul>
          <li>Kennlicht</li>
          <li>Vorsichtssignal</li>
          <li>Ersatzsignal (mittig)</li>
          <li>Verkürzter Bremswegabstand</li>
        </ul>
      </td>
    </tr>
  </tbody>
</table>

## Vorsignale

<table width="100%">
  <thead>
    <tr>
      <th colspan="2">Vorschau</th>
      <th>Anmerkungen</th>
    </tr>
  </thead>
  <tbody>
    <tr>
      <td width="200" align="center">
        
        <br>
        <a href="export/VS.step">STEP</a> · <a href="export/VS.stl">STL</a>
      </td>
      <td width="200" align="center"></td>
      <td>
        <p>
          <em>VS</em>
        </p>
      </td>
    </tr>
    <tr>
      <td width="200" align="center">
        
        <br>
        <a href="export/VS_Wd.step">STEP</a> · <a href="export/VS_Wd.stl">STL</a>
      </td>
      <td width="200" align="center"></td>
      <td>
        <p>
          <em>VS_Wd</em>
        </p>
        <ul>
          <li>Wiederholer</li>
        </ul>
      </td>
    </tr>
    <tr>
      <td width="200" align="center">
        
        <br>
        <a href="export/VS_vBw.step">STEP</a> · <a href="export/VS_vBw.stl">STL</a>
      </td>
      <td width="200" align="center"></td>
      <td>
        <p>
          <em>VS_vBw</em>
        </p>
        <ul>
          <li>Verkürzter Bremswegabstand</li>
        </ul>
      </td>
    </tr>
  </tbody>
</table>

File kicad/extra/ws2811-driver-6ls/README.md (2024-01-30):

# WS2811 LED Driver 6LS

A WS2811 LED driver board compatible with [MGP signal decoders](http://www.mollehem.se/index.php/en/signals/signal-decoders/signaldecoder-de10-detail).

This LED driver board provides 4 LEDs via one 2x3p 1.27 mm pitch connectors, intended for one German light switching signals.



## Notes

This board can be connected via three methods:

1. RJ45 cabling as used by signal mount drivers and described in the [adapter board README](../ws2811-adapter/README.md).
2. Regular three-pin headers or servo connectors via J2 and J5.
3. Soldered wires via J3 and J6.

## Pinout

The 2x3 1.27mm pitch connectors have the following pinout:



| LED | Pin | Notes |
| --- | --- | --- |
| | 1 | Vcc |
| 1 | 2 | Red 1 (LS-alt) |
| 2 | 4 | White 1 |
| 3 | 6 | Red 2 (LS-alt / LS-neu) |
| 4 | 5 | White 2 |

## License

This work is licensed under a
[Creative Commons Attribution-ShareAlike 4.0 International License](http://creativecommons.org/licenses/by-sa/4.0/).

CC-BY-SA 4.0 (http://creativecommons.org/licenses/by-sa/4.0/)

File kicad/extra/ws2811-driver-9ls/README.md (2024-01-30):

# WS2811 LED Driver 9LS

A WS2811 LED driver board compatible with [MGP signal decoders](http://www.mollehem.se/index.php/en/signals/signal-decoders/signaldecoder-de10-detail).

This LED driver board provides 8 LEDs via two 2x3p 1.27 mm pitch connectors, intended for up to two German light switching signals.



## Notes

This board can be connected via three methods:

1. RJ45 cabling as used by signal mount drivers and described in the [adapter board README](../ws2811-adapter/README.md).
2. Regular three-pin headers or servo connectors via J2 and J5.
3. Soldered wires via J3 and J6.

## Pinout

The 2x3 1.27mm pitch connectors have the following pinout:



| LED | Pin | Notes |
| --- | --- | --- |
| | 1 | Vcc |
| 1 | 2 | Red 1 (LS-alt) |
| 2 | 4 | White 1 |
| 3 | 6 | Red 2 (LS-alt / LS-neu) |
| 4 | 5 | White 2 |

## License

This work is licensed under a
[Creative Commons Attribution-ShareAlike 4.0 International License](http://creativecommons.org/licenses/by-sa/4.0/).

CC-BY-SA 4.0 (http://creativecommons.org/licenses/by-sa/4.0/)

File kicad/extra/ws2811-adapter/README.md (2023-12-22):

# WS2811 Adapter

Adapter PCB to connect Watti LED driver boards via RJ45 cables to [MGP signal decoders](http://www.mollehem.se/index.php/en/signals/signal-decoders/signaldecoder-de10-detail). The adapter board supports connecting multiple RJ45 loops in a chain.



## Schema

Electronic schema

The control signal from the signal decoder consists of three wires, a ground and power line, and a single data wire. The signals are passed on to the RJ45 cables:

| RJ45 | Purpose |
| ---- | --- |
| 1 | Returned data signal |
| 2 | GND |
| 3 | GND |
| 4 | VCC (Power) |
| 5 | VCC (Power) |
| 6 | GND |
| 7 | Data signal |
| 8 | GND |

### Outgoing and returned data signal

LED on driver boards are controlled by the physical ordering on the data signal line. To order signals in a specific ordering, the RJ45 pinout supports returning the data signal from one RJ45 cable and pass it to the next. The last Watti LED driver must have the jumper JR1 set to "ON", to return the data signal line to the adapter board.

This allows ordering signals a convenient way for programming. For example, assume you want to program a single decoder to control the entry signal and pre-signal, and optional the entry signal and pre-signal for the opposite track.

If you connect the signals via a single RJ45 line with short distance, you might want to connect them in this order:

| Index | Signal | Logical LED numbers |
| ----- | --- | --- |
| 1 | Entry signal | LED 1-12 |
| 2 | Entry signal (opposite track) | LED 13-24 |
| 3 | Pre-entry signal | LED 25-36 |
| 4 | Pre-entry signal (opposite track) | LED 37-48 |

If you now want to change your module layout to a setup without opposite track signals, the logical LED numbers programmed into the decoder wouldn't match the pre-entry signal for the regular track anymore.

| Index | Signal | Logical LED numbers |
| ----- | --- | --- |
| 1 | Entry signal | LED 1-12 |
| 2 | Pre-entry signal | LED 13-24 ⚠ |

To support such reconfiguration without reprogramming, the data signal can be routed differently:

Data signal line flow

## License

This work is licensed under a
[Creative Commons Attribution-ShareAlike 4.0 International License](http://creativecommons.org/licenses/by-sa/4.0/).

(http://creativecommons.org/licenses/by-sa/4.0/)

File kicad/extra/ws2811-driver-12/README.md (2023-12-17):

# WS2811 LED Driver 12

A WS2811 LED driver board compatible with [MGP signal decoders](http://www.mollehem.se/index.php/en/signals/signal-decoders/signaldecoder-de10-detail) and the [Wattenscheider signal mount](https://www.fremo-net.eu/index.php?id=339).

This LED driver board provides 12 LEDs, intended for up to one fully equipped German KS signal.



## Notes

1. Connect the RJ45 cable from the adapter board to the RJ45 plug labeled "INPUT".
2. Connect the RJ45 cable to the next signal from the "OUTPUT" plug.
3. If you do not connect an outgoing RJ45 cable, you can set the jumper JP1 to "ON" to route the data signal back to the adapter board. See more at the [adapter board README](../ws2811-adapter/README.md).

## License

This work is licensed under a
[Creative Commons Attribution-ShareAlike 4.0 International License](http://creativecommons.org/licenses/by-sa/4.0/).

(http://creativecommons.org/licenses/by-sa/4.0/)

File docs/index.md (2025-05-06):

# Eisenbahnsignale

<em lang="en">
This project contains 3d models, parts, and electronic components and boards to build german railway signals for H0 model railroading.
</em>

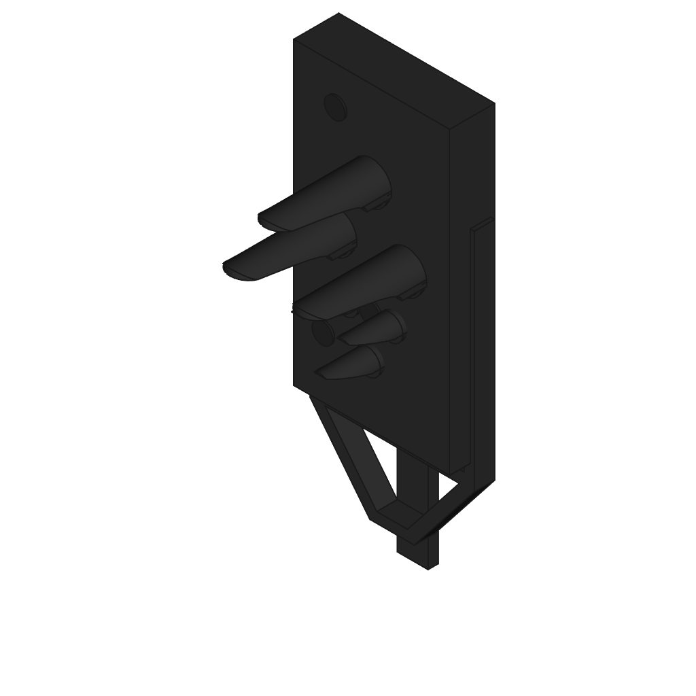
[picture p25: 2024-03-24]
freecad/KS/Signalschirme/export/MS_Zs7__A-axo.png

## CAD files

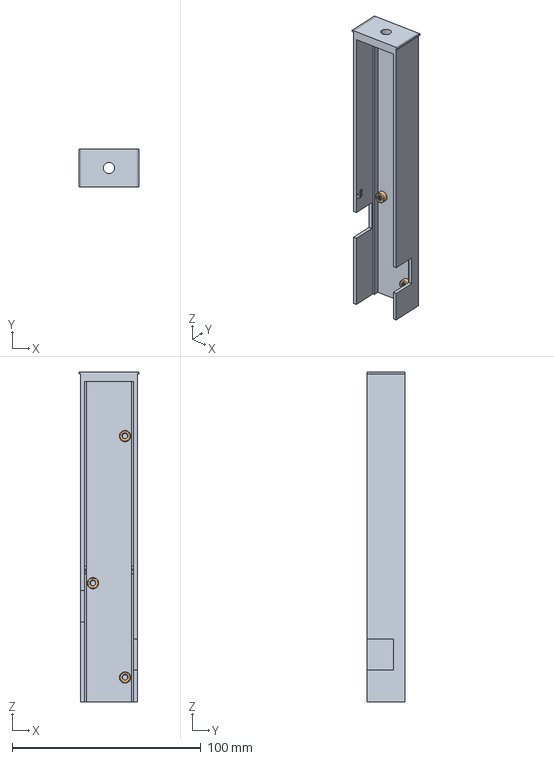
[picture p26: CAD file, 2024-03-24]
freecad/watti-signal-mount/export/watti-w-latch-assembly.step
32.0 x 20.0 x 175.0 mm

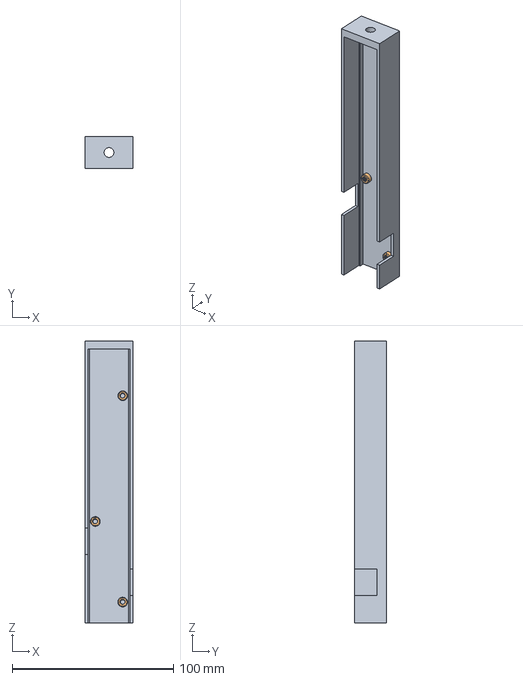
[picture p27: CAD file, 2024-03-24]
freecad/watti-signal-mount/export/watti-assembly.step
30.0 x 20.0 x 175.0 mm

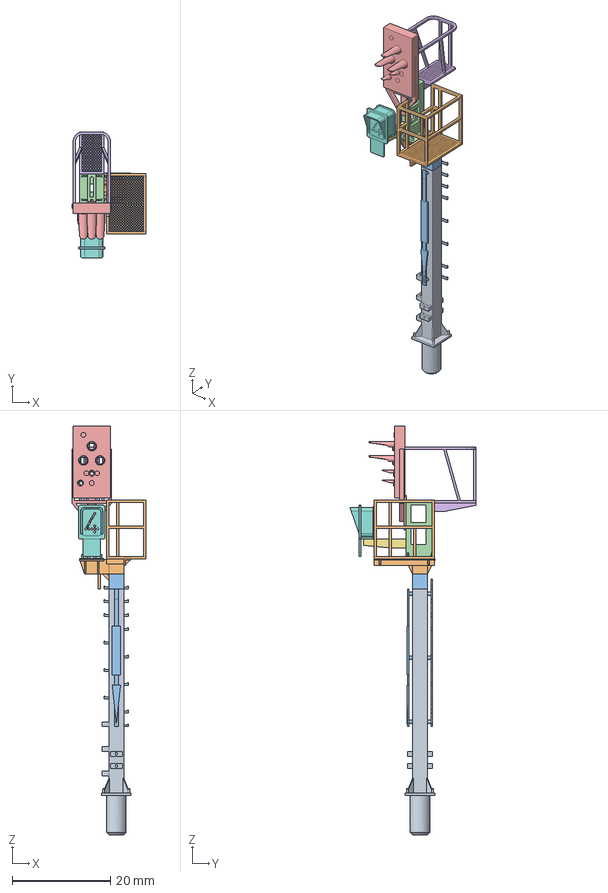
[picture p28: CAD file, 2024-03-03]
freecad/KS/Example/MS_48_40_1.FCStd
15.0 x 25.7 x 83.1 mm
Part_Ausleger_Mast_42_001
Part_Ausleger_40_001
Part_Auslegermount_ASM_001
Part_Ausleger_Signalmast_1ZS_001
MS_Sh1_001
Mast_Korb_1_001
ZS_Halterung_001
ZS_Zs3_4_NR_001
Leiter_26_001
Mast_Auslegerkorb_40_001
Mastschild_26_MS_001

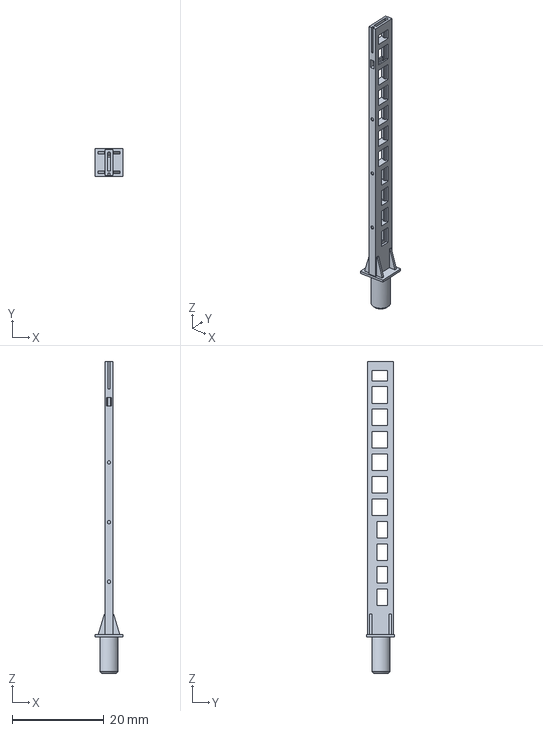
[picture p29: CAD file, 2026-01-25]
freecad/KS/Masten/export/Gittermast_60_1ZS.step
6.00 x 6.00 x 68.0 mm

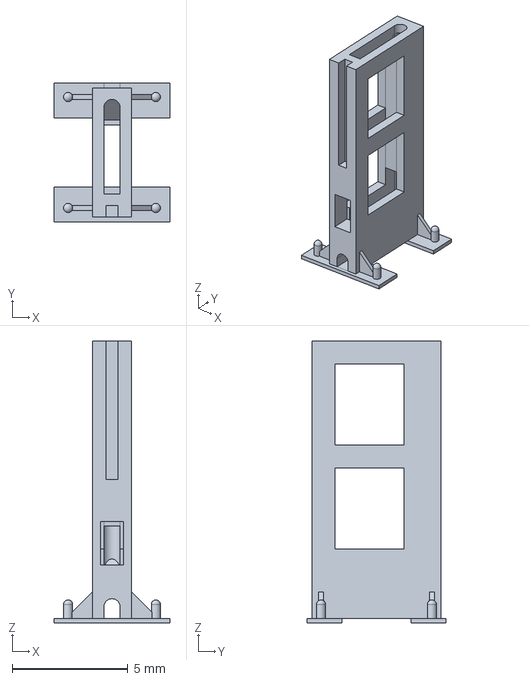
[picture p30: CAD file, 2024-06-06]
freecad/KS/Masten/parts/Part_Signalmast_1ZS.FCStd
5.00 x 6.00 x 12.2 mm

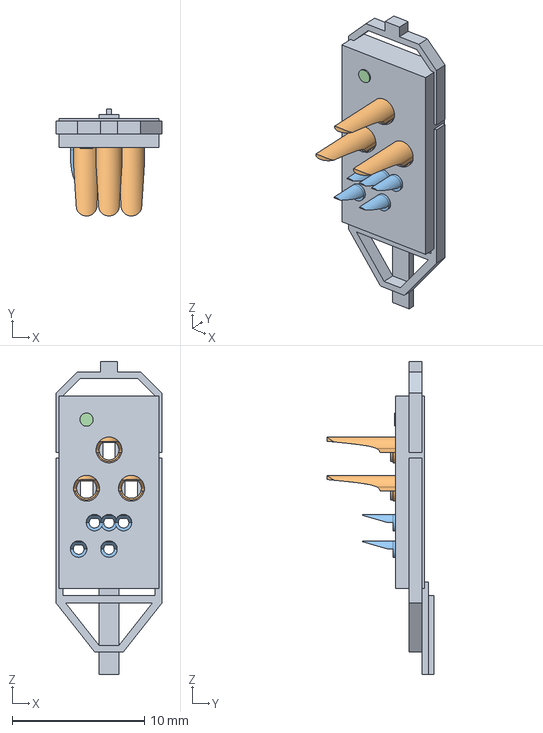
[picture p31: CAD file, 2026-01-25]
freecad/KS/Signalschirme/export/MS_Zs7_Sh1__B.step
8.00 x 8.10 x 23.7 mm

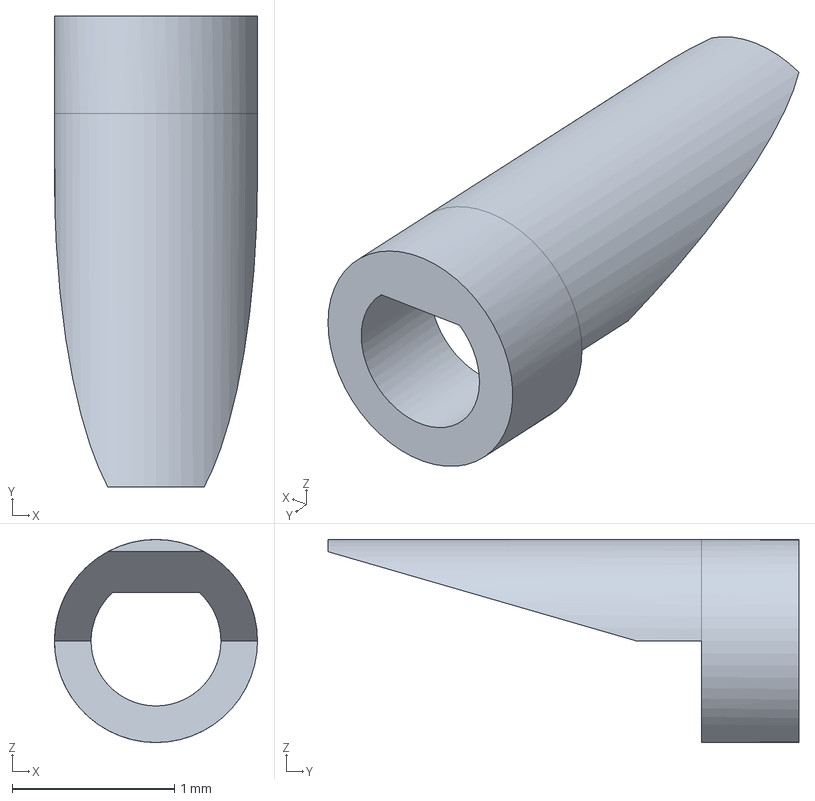
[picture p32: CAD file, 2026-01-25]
freecad/KS/Signalschirme/parts/HS_Schute_10.FCStd
1.25 x 2.90 x 1.25 mm

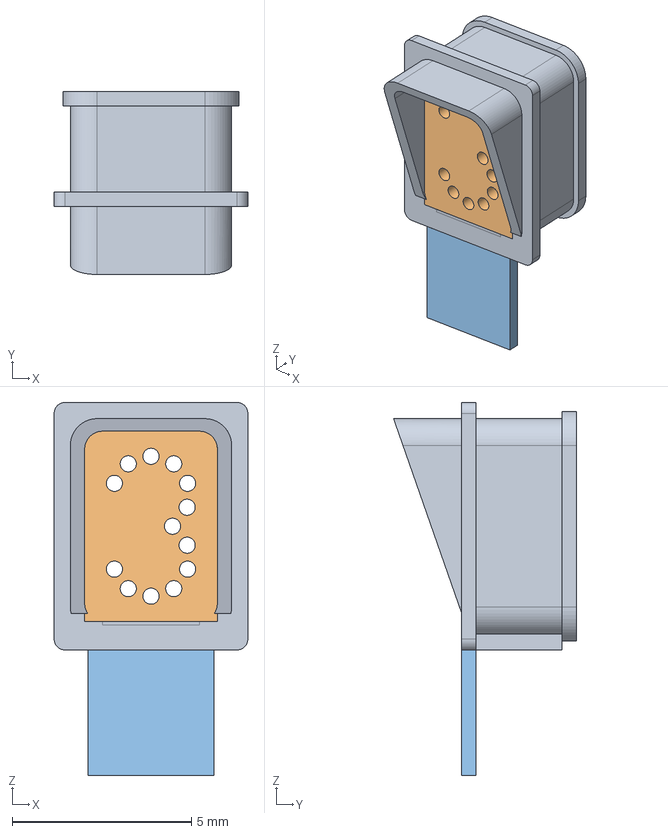
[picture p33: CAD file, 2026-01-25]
freecad/KS/Zusatzsignale/export/ZS_Zs3_3_NR.step
5.40 x 5.10 x 10.4 mm

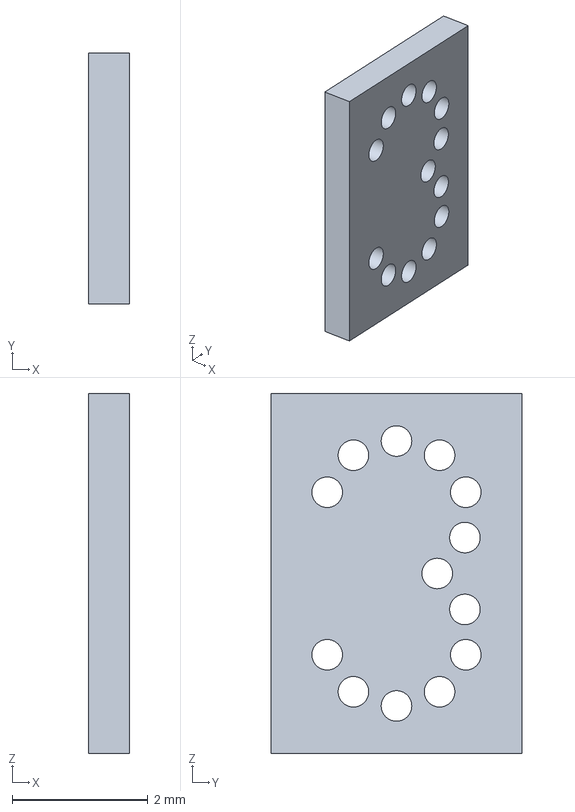
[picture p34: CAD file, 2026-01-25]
freecad/KS/Zusatzsignale/parts/ZS_Tafel_3.FCStd
0.6 x 3.70 x 5.30 mm

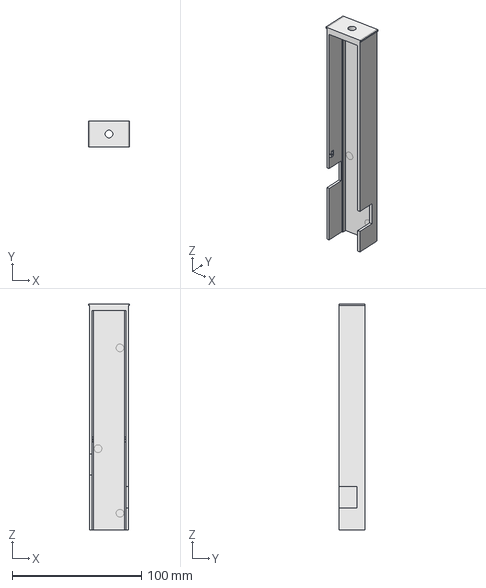
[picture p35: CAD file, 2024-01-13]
freecad/watti-signal-mount/parts/watti-body-w-latch.FCStd
32.0 x 20.0 x 175.0 mm

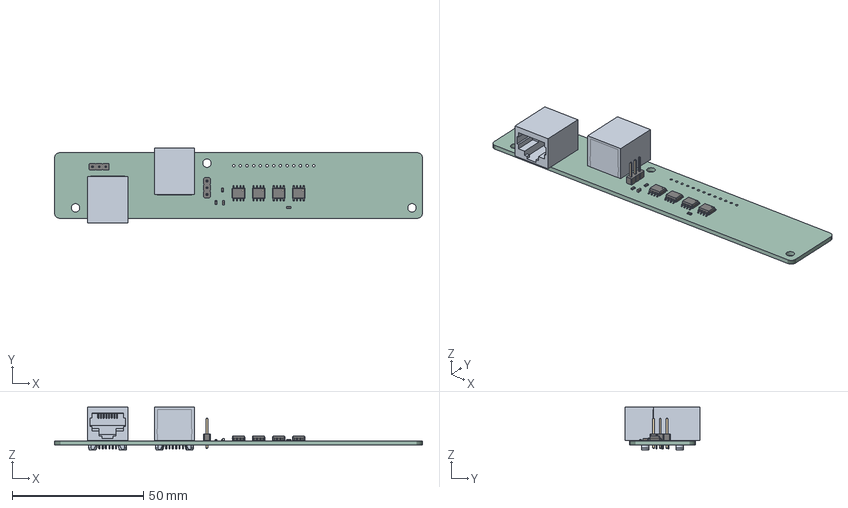
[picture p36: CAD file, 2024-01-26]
kicad/extra/ws2811-driver-12/ws2811-driver-12.step
140.0 x 28.4 x 16.2 mm
C_0603_1608Metric
R_0603_1608Metric x 3
54602-908_SW0002 x 2
PinHeader_1x03_P254mm_Vertical x 2
SOIC_8_39x49mm_P127mm x 4
ws2811-driver-12 PCB

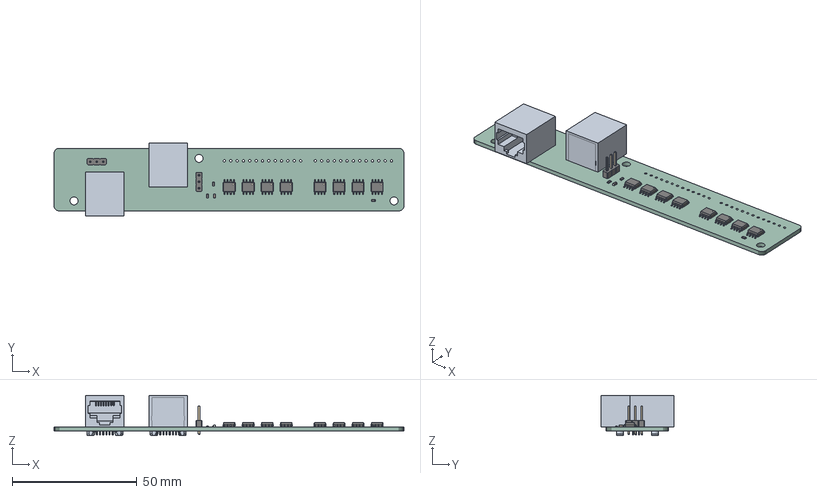
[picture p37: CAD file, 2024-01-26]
kicad/extra/ws2811-driver-24/ws2811-driver-24.step
140.0 x 29.3 x 16.2 mm
SOIC_8_39x49mm_P127mm x 8
C_0603_1608Metric
PinHeader_1x03_P254mm_Vertical x 2
R_0603_1608Metric x 3
54602-908_SW0002 x 2
ws2811-driver-24 PCB

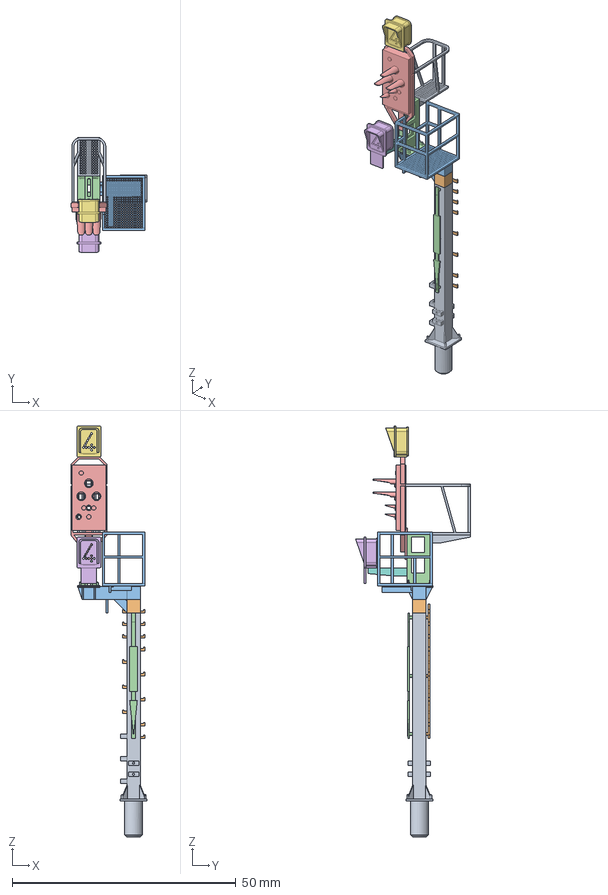
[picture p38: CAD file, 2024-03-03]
freecad/KS/Example/MS_48_80_1.FCStd
17.0 x 25.7 x 91.8 mm
Part_Ausleger_Mast_42_001
Part_Auslegermount_ASM_001
Part_Ausleger_80_001
Part_Ausleger_Signalmast_1ZS_001
MS_Zs_Sh1_001
ZS_Zs3_4_NR_001
ZS_Zs3_4_001
ZS_Halterung_001
Mast_Korb_1_001
Leiter_26_0504_001
Mast_Auslegerkorb_80_001
Mastschild_26_MS_001

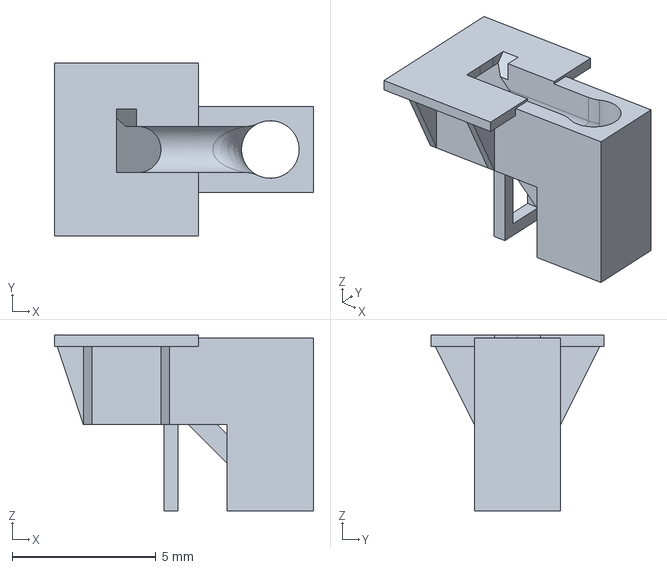
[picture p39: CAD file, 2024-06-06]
freecad/KS/Masten/parts/Part_Ausleger_40.FCStd
9.00 x 6.00 x 6.10 mm

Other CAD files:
freecad/KS/Masten/export/Gittermast_60_2ZS.step
freecad/KS/Signalschirme/export/MS_Zs7_Sh1_vBw__B.step
freecad/KS/Signalschirme/parts/HS_Schute_15.FCStd
freecad/KS/Zusatzsignale/export/ZS_Zs3_3.step
freecad/KS/Masten/Auslegermast_48_40L_1ZS.FCStd
freecad/KS/Masten/Auslegermast_48_40R_1ZS.FCStd
freecad/KS/Masten/Gittermast_60_1ZS.FCStd
freecad/KS/Masten/Gittermast_60_2ZS.FCStd
freecad/KS/Masten/Leiter_16.FCStd
freecad/KS/Masten/Leiter_16_0504.FCStd
freecad/KS/Masten/Leiter_26.FCStd
freecad/KS/Masten/Leiter_26_0504.FCStd
freecad/KS/Masten/Mast_Korb_1.FCStd
freecad/KS/Masten/Mastschild_16_MS.FCStd
freecad/KS/Masten/Mastschild_16_VS.FCStd
freecad/KS/Masten/Mastschild_26_MS.FCStd
freecad/KS/Masten/Mastschild_26_VS.FCStd
freecad/KS/Masten/Sockel.FCStd
freecad/KS/Masten/Technik_1.FCStd
freecad/KS/Masten/export/Ausleger_Mast_32.stl
freecad/KS/Masten/export/Ausleger_Mast_42.stl
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

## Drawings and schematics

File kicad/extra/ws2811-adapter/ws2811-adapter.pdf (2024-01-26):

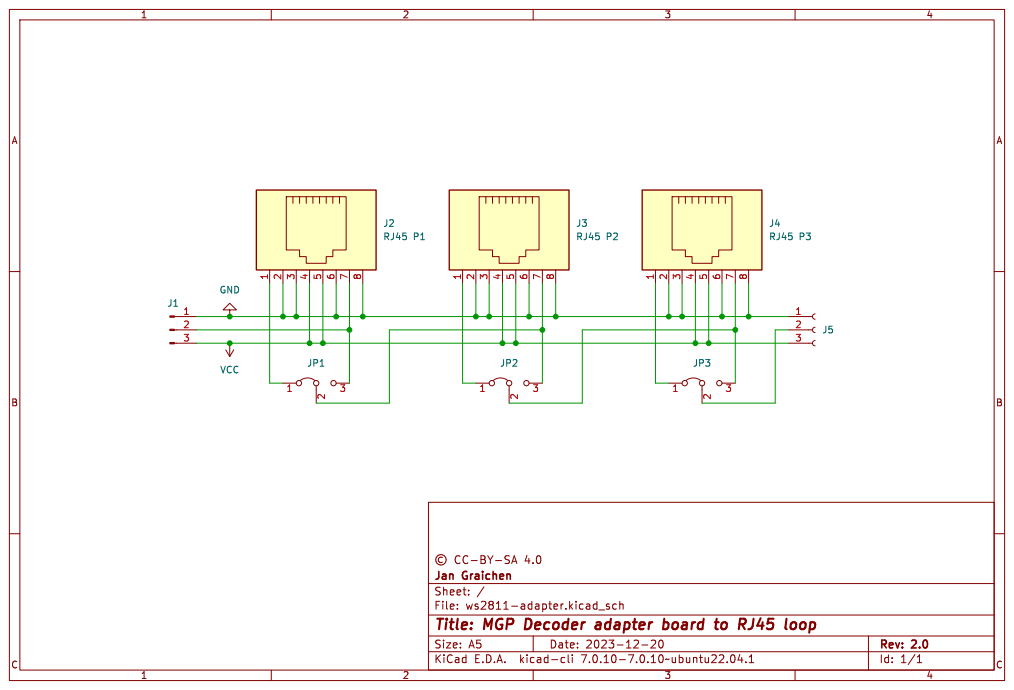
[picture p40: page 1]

File: ws2811-adapter.kicad_sch Sheet: / Jan Graichen

Id: 1/1 Title: MGP Decoder adapter board to RJ45 loop

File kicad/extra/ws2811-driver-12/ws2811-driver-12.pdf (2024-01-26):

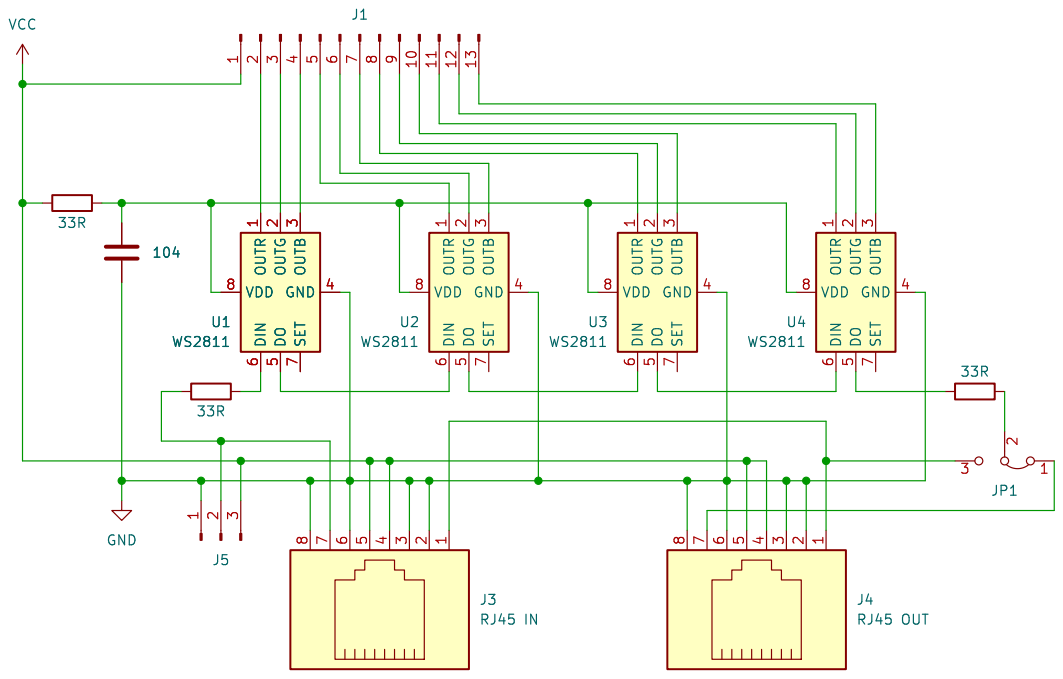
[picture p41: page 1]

Id: 1/1 Title: WS2811 LED Driver 12 (1 Signal) File: ws2811-driver-12.kicad_sch Sheet: / Jan Graichen

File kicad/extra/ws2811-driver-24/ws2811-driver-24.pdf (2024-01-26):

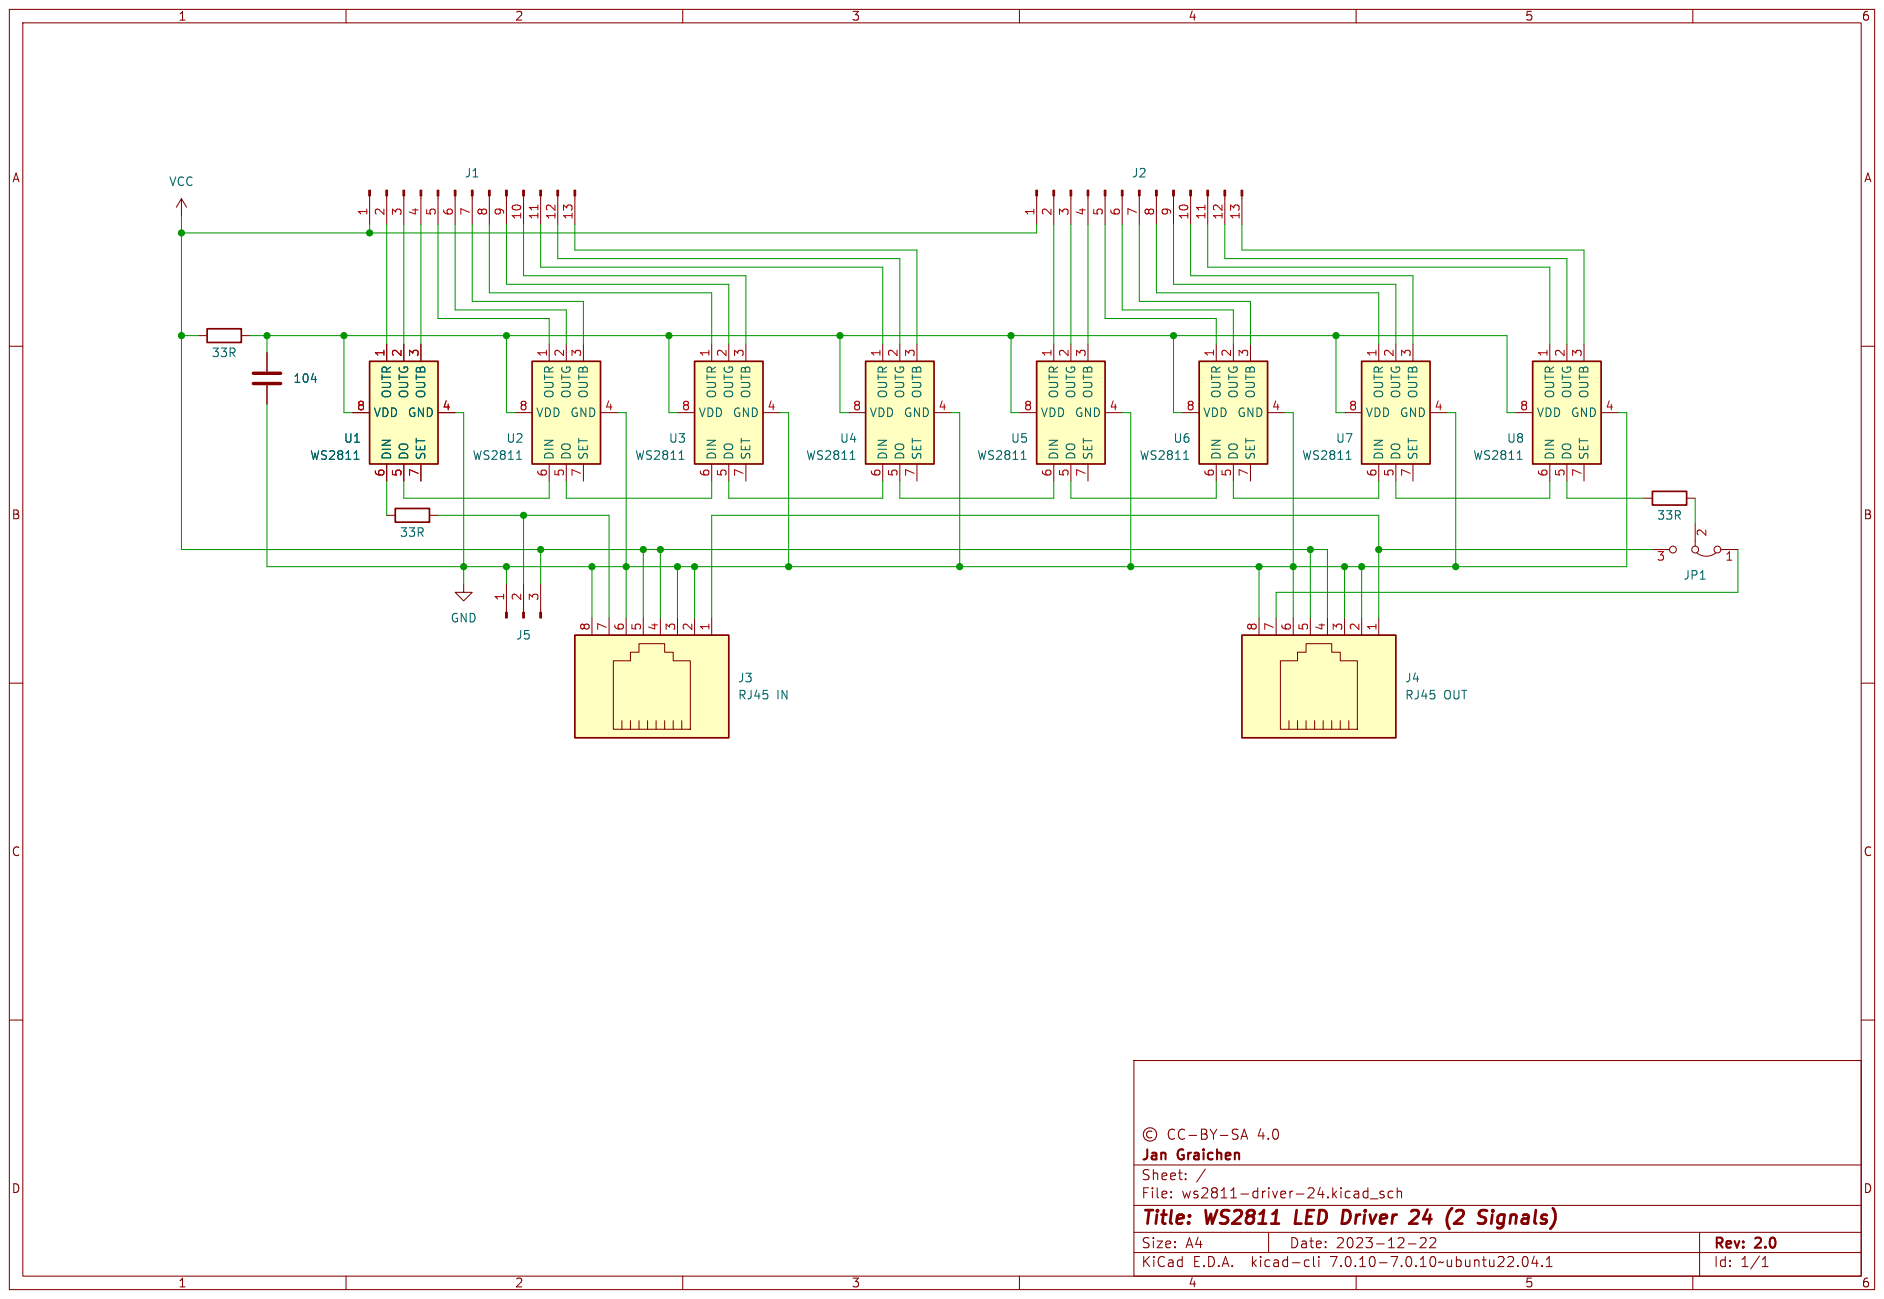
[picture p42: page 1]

Id: 1/1 Title: WS2811 LED Driver 24 (2 Signals) File: ws2811-driver-24.kicad_sch Sheet: / Jan Graichen

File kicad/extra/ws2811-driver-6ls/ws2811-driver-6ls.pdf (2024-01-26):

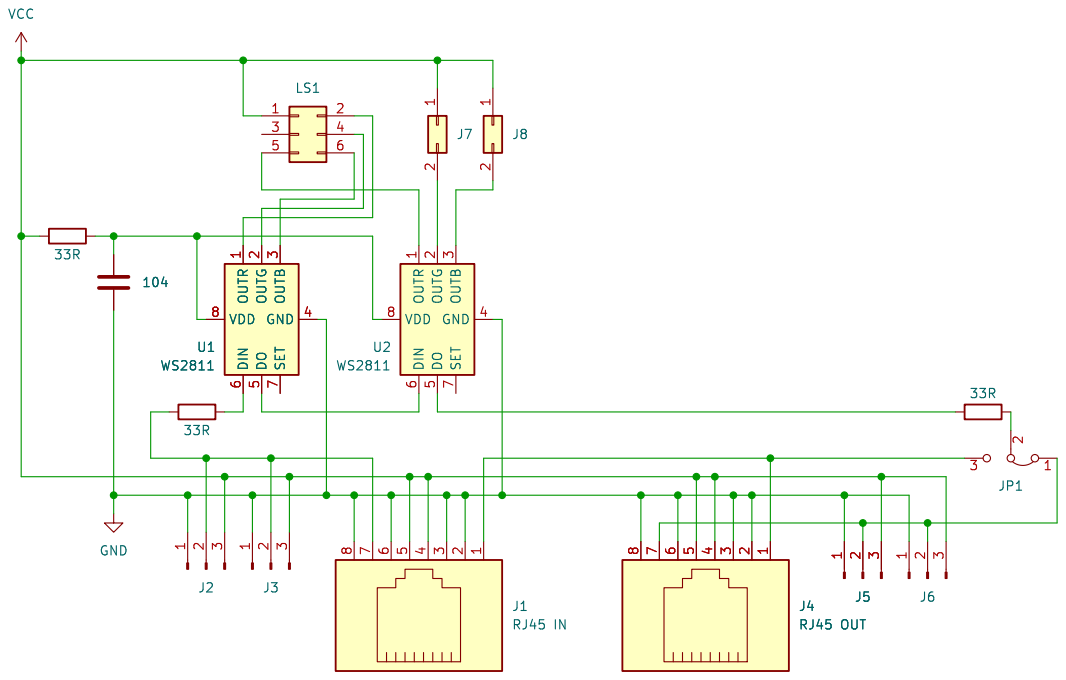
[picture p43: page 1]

Id: 1/1 Title: WS2811 LED Driver 6LS (1 Lichtsperrsignal) File: ws2811-driver-6ls.kicad_sch Sheet: / Jan Graichen

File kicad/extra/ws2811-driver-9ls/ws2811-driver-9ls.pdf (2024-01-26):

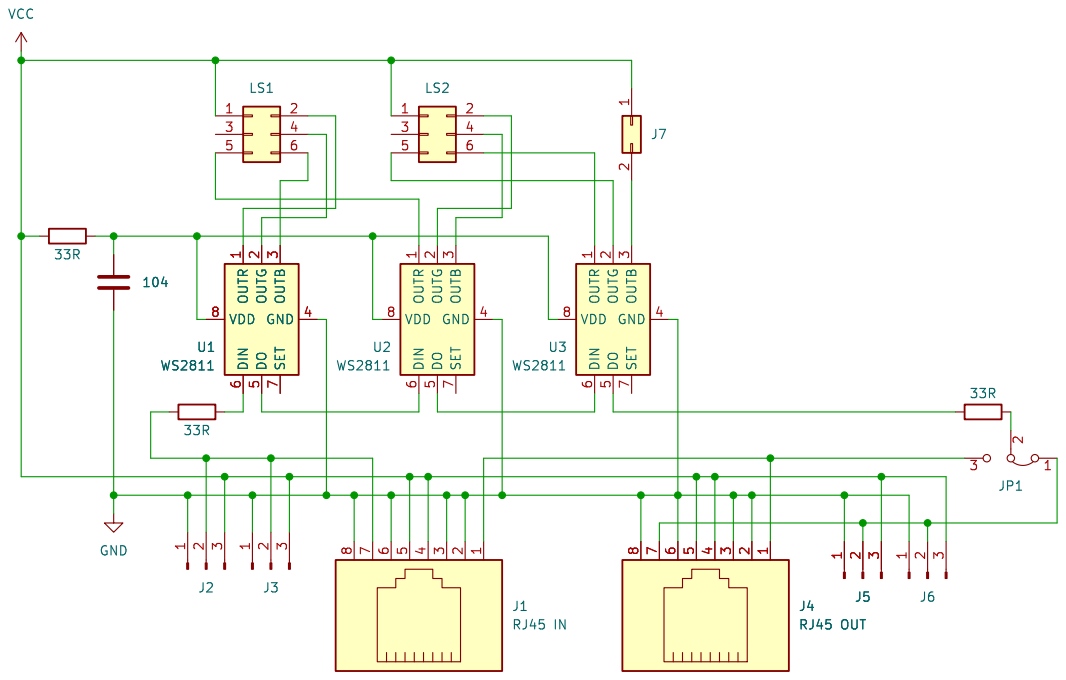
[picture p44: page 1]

Id: 1/1 Title: WS2811 LED Driver 9LS (2 Lichtsperrsignale) File: ws2811-driver-9ls.kicad_sch Sheet: / Jan Graichen

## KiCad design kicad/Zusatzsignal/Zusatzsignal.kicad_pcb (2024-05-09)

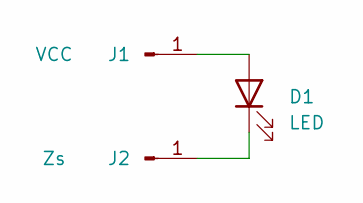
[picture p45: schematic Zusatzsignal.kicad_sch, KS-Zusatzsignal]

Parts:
D1: LED; LED_0603_1608Metric
J1: VCC; SolderWirePad_1x01_SMD_1x2mm
J2: Zs; SolderWirePad_1x01_SMD_1x2mm

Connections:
unnamed: D1.1 (K), J2.1
unnamed: D1.2 (A), J1.1

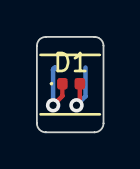
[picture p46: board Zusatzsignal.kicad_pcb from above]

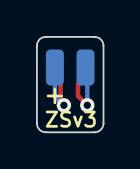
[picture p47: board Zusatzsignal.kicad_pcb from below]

Board: 2 copper layers, 3.7 x 5.3 mm, 3 parts (2 on the bottom side), 2 nets.

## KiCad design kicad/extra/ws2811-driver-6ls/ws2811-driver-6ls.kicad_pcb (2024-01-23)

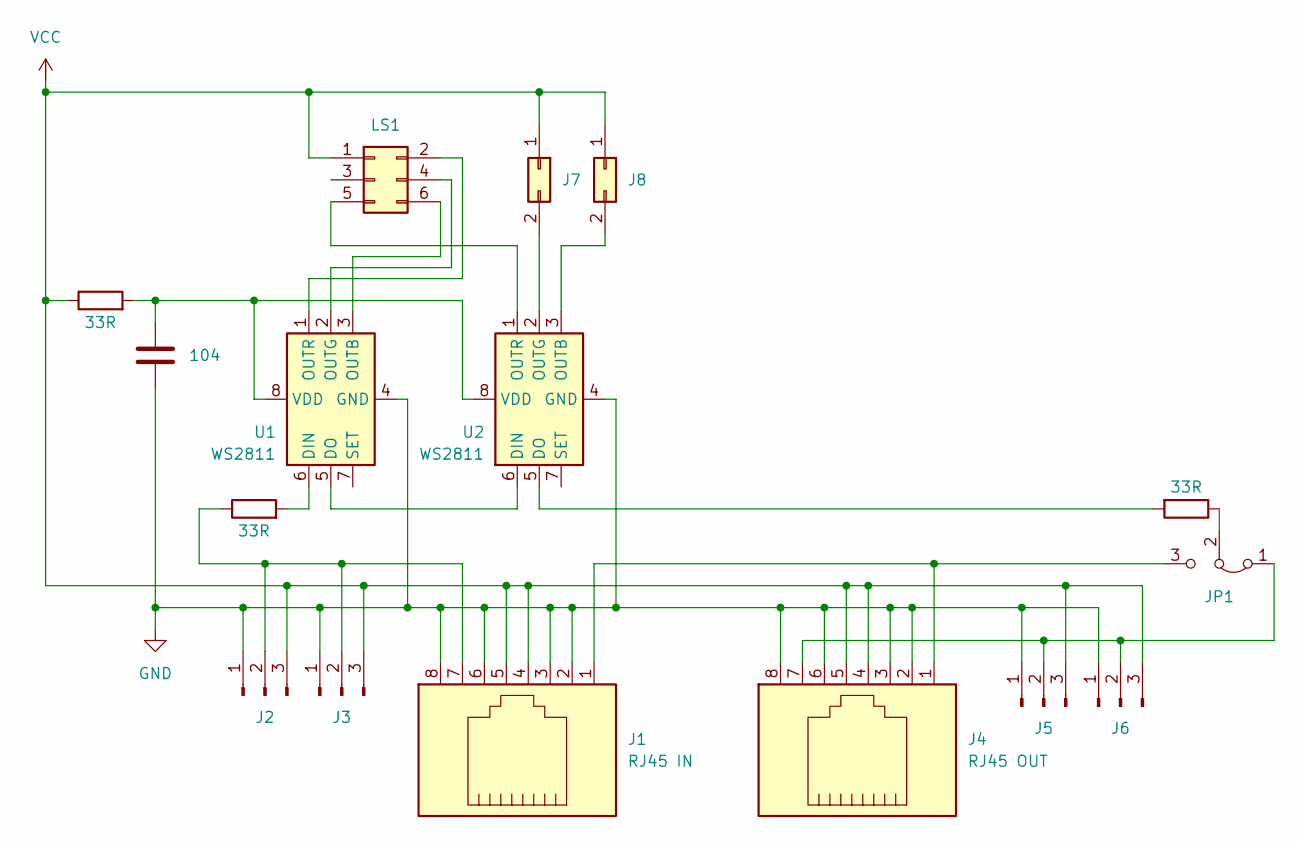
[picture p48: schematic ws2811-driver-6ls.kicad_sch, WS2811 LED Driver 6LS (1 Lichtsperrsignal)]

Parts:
C1: 104; C_0603_1608Metric; LCSC C14663
J1: RJ45 IN; RJ45_Amphenol_54602-x08_Horizontal
J2, J5: Conn_01x03_Pin; PinHeader_1x03_P2.54mm_Vertical
J3, J6: Conn_01x03_Pin; SolderWire-0.15sqmm_1x03_P4mm_D0.5mm_OD1.5mm_Relief
J4: RJ45 OUT; RJ45_Amphenol_54602-x08_Horizontal
J7, J8: Conn_02x01; PinHeader_2x01_P1.27mm_Vertical
JP1: Jumper_3_Bridged12; PinHeader_1x03_P2.54mm_Vertical
LS1: Conn_02x03_Odd_Even; PinHeader_2x03_P1.27mm_Vertical
R1, R2, R3: 33R; R_0603_1608Metric; LCSC C23140
U1, U2: WS2811; SOIC-8_3.9x4.9mm_P1.27mm; LCSC C114581

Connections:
GND: C1.2, J1.2, J1.3, J1.6, J1.8, J2.1, J3.1, J4.2, J4.3, J4.6, J4.8, J5.1, J6.1, U1.4 (GND), U2.4 (GND)
unnamed: J1.7, J2.2, J3.2, R2.1
unnamed: J4.7, J5.2, J6.2, JP1.1 (A)
unnamed: J7.2, U2.2 (OUTG)
unnamed: J8.2, U2.3 (OUTB)
unnamed: J1.1, J4.1, JP1.3 (B)
unnamed: JP1.2 (C), R3.1
unnamed: LS1.2, U1.1 (OUTR)
unnamed: LS1.4, U1.2 (OUTG)
unnamed: LS1.5, U2.1 (OUTR)
unnamed: LS1.6, U1.3 (OUTB)
unnamed: R2.2, U1.6 (DIN)
unnamed: U1.5 (DO), U2.6 (DIN)
unnamed: C1.1, R1.2, U1.8 (VDD), U2.8 (VDD)
unnamed: R3.2, U2.5 (DO)
VCC: J1.4, J1.5, J2.3, J3.3, J4.4, J4.5, J5.3, J6.3, J7.1, J8.1, LS1.1, R1.1

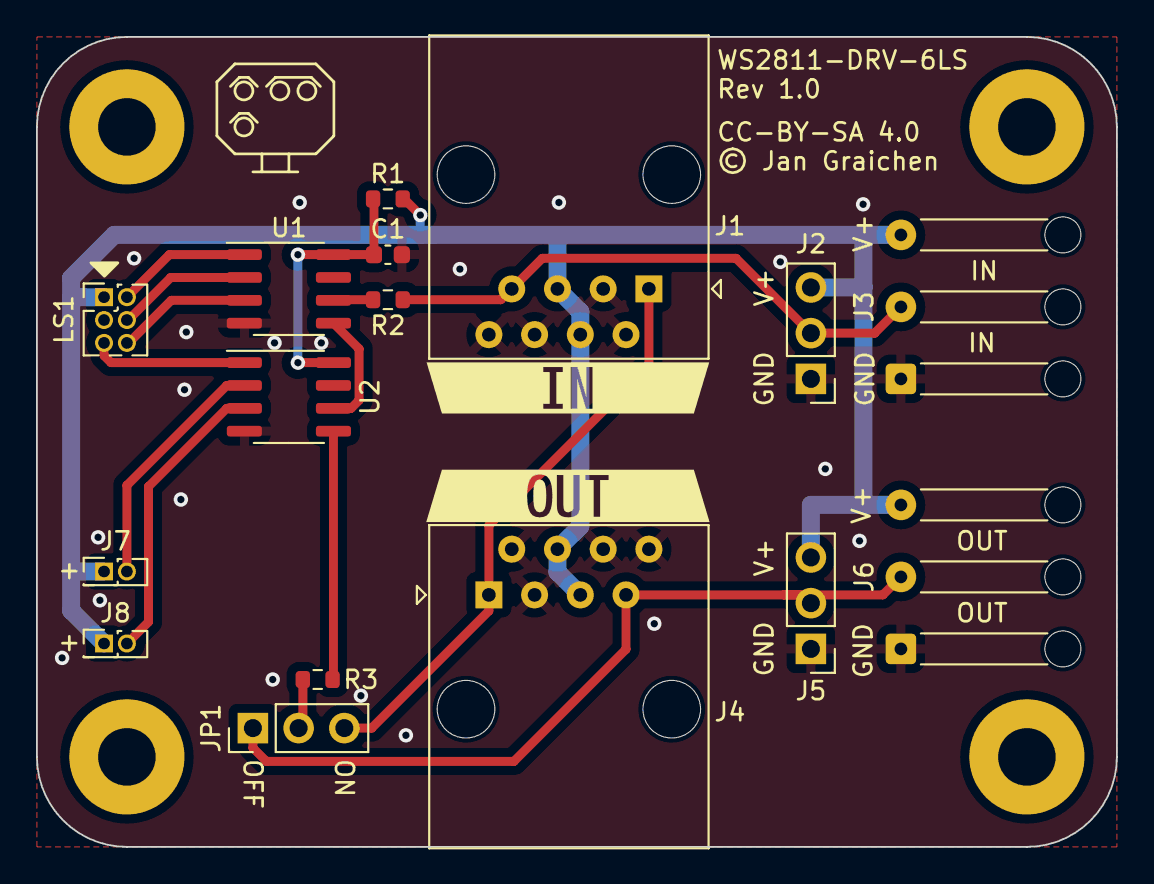
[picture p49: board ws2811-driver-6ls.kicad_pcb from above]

Board: 2 copper layers, 60.0 x 45.0 mm, 18 parts (0 on the bottom side), 16 nets.

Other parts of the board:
kibuzzard-65AE6F8F: G***; kibuzzard-65AE6F8F
kibuzzard-65AE6F95: G***; kibuzzard-65AE6F95

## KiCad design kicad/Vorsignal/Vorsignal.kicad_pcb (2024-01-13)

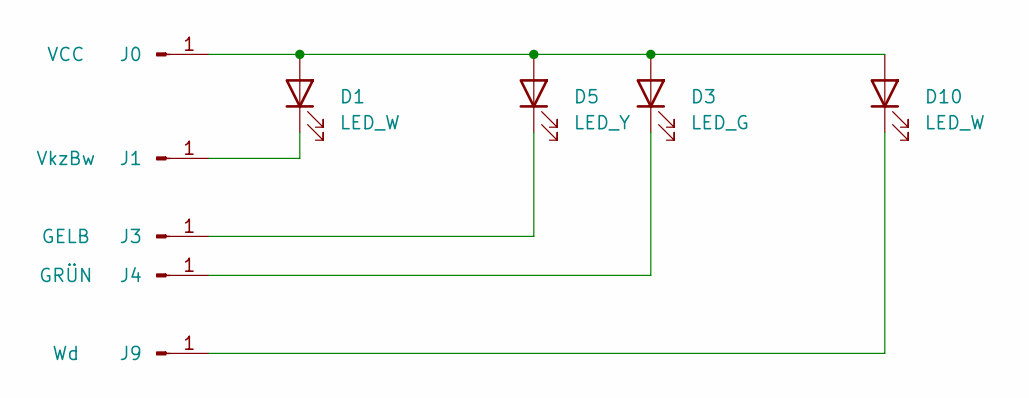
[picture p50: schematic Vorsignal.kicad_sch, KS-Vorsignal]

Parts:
D1, D10: LED_W; LED_0402_1005Metric; LCSC C189305
D3: LED_G; LED_0402_1005Metric; LCSC C409787
D5: LED_Y; LED_0402_1005Metric; LCSC C779450
J0: VCC; SolderWirePad_1x01_SMD_1x2mm
J1: VkzBw; SolderWirePad_1x01_SMD_1x2mm
J3: GELB; SolderWirePad_1x01_SMD_1x2mm
J4: GRÜN; SolderWirePad_1x01_SMD_1x2mm
J9: Wd; SolderWirePad_1x01_SMD_1x2mm

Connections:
unnamed: D1.2 (A), D3.2 (A), D5.2 (A), D10.2 (A), J0.1
unnamed: D1.1 (K), J1.1
unnamed: D3.1 (K), J4.1
unnamed: D5.1 (K), J3.1
unnamed: D10.1 (K), J9.1

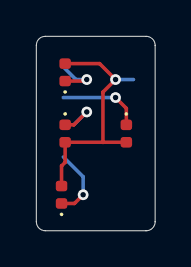
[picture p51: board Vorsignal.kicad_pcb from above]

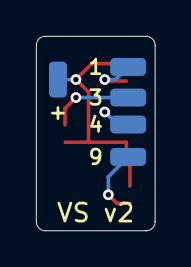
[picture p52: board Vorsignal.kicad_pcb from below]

Board: 2 copper layers, 6.6 x 10.8 mm, 9 parts (5 on the bottom side), 5 nets.

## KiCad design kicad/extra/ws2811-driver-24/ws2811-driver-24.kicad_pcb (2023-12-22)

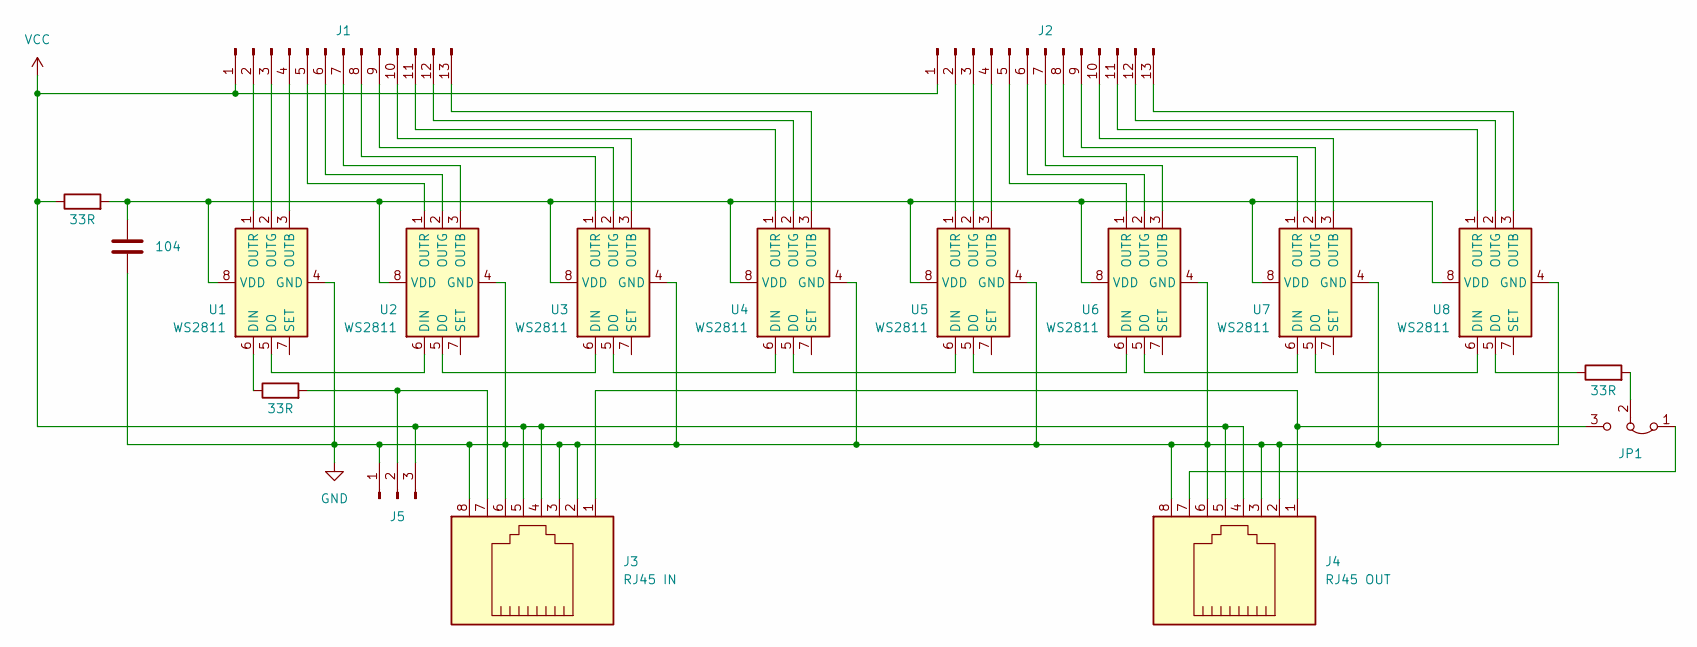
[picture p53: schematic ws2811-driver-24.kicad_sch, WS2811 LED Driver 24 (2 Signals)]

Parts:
C1: 104; C_0603_1608Metric
J1, J2: Conn_01x13_Pin; PinHeader_1x13_P2.54mm_Vertical
J3: RJ45 IN; RJ45_Amphenol_54602-x08_Horizontal
J4: RJ45 OUT; RJ45_Amphenol_54602-x08_Horizontal
J5: Conn_01x03_Pin; PinHeader_1x03_P2.54mm_Vertical
JP1: Jumper_3_Bridged12; PinHeader_1x03_P2.54mm_Vertical
R1, R2, R3: 33R; R_0603_1608Metric
U1, U2, U3, U4, U5, U6, U7, U8: WS2811; SOIC-8_3.9x4.9mm_P1.27mm

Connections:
GND: C1.2, J3.2, J3.3, J3.6, J3.8, J4.2, J4.3, J4.6, J4.8, J5.1, U1.4 (GND), U2.4 (GND), U3.4 (GND), U4.4 (GND), U5.4 (GND), U6.4 (GND), U7.4 (GND), U8.4 (GND)
unnamed: J1.2, U1.1 (OUTR)
unnamed: J1.3, U1.2 (OUTG)
unnamed: J1.4, U1.3 (OUTB)
unnamed: J1.5, U2.1 (OUTR)
unnamed: J1.6, U2.2 (OUTG)
unnamed: J1.7, U2.3 (OUTB)
unnamed: J1.8, U3.1 (OUTR)
unnamed: J1.9, U3.2 (OUTG)
unnamed: J1.10, U3.3 (OUTB)
unnamed: J1.11, U4.1 (OUTR)
unnamed: J1.12, U4.2 (OUTG)
unnamed: J1.13, U4.3 (OUTB)
unnamed: J2.2, U5.1 (OUTR)
unnamed: J2.3, U5.2 (OUTG)
unnamed: J2.4, U5.3 (OUTB)
unnamed: J2.5, U6.1 (OUTR)
unnamed: J2.6, U6.2 (OUTG)
unnamed: J2.7, U6.3 (OUTB)
unnamed: J2.8, U7.1 (OUTR)
unnamed: J2.9, U7.2 (OUTG)
unnamed: J2.10, U7.3 (OUTB)
unnamed: J2.11, U8.1 (OUTR)
unnamed: J2.12, U8.2 (OUTG)
unnamed: J2.13, U8.3 (OUTB)
unnamed: J3.7, J5.2, R2.2
unnamed: J4.7, JP1.1 (A)
unnamed: J3.1, J4.1, JP1.3 (B)
unnamed: JP1.2 (C), R3.2
unnamed: R2.1, U1.6 (DIN)
unnamed: U1.5 (DO), U2.6 (DIN)
unnamed: C1.1, R1.2, U1.8 (VDD), U2.8 (VDD), U3.8 (VDD), U4.8 (VDD), U5.8 (VDD), U6.8 (VDD), U7.8 (VDD), U8.8 (VDD)
unnamed: U2.5 (DO), U3.6 (DIN)
unnamed: U3.5 (DO), U4.6 (DIN)
unnamed: U4.5 (DO), U5.6 (DIN)
unnamed: U5.5 (DO), U6.6 (DIN)
unnamed: U6.5 (DO), U7.6 (DIN)
unnamed: U7.5 (DO), U8.6 (DIN)
unnamed: R3.1, U8.5 (DO)
VCC: J1.1, J2.1, J3.4, J3.5, J4.4, J4.5, J5.3, R1.1

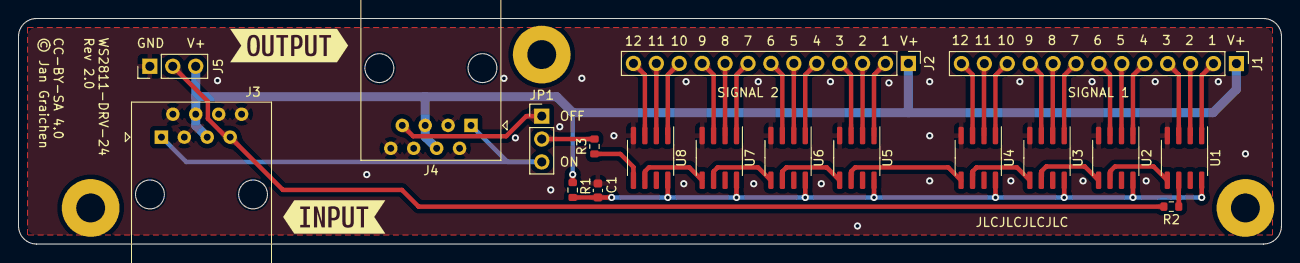
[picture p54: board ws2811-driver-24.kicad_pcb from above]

Board: 2 copper layers, 140.0 x 25.0 mm, 20 parts (0 on the bottom side), 40 nets.

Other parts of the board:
kibuzzard-6563A51A: G***; kibuzzard-6563A51A
kibuzzard-6563A507: G***; kibuzzard-6563A507

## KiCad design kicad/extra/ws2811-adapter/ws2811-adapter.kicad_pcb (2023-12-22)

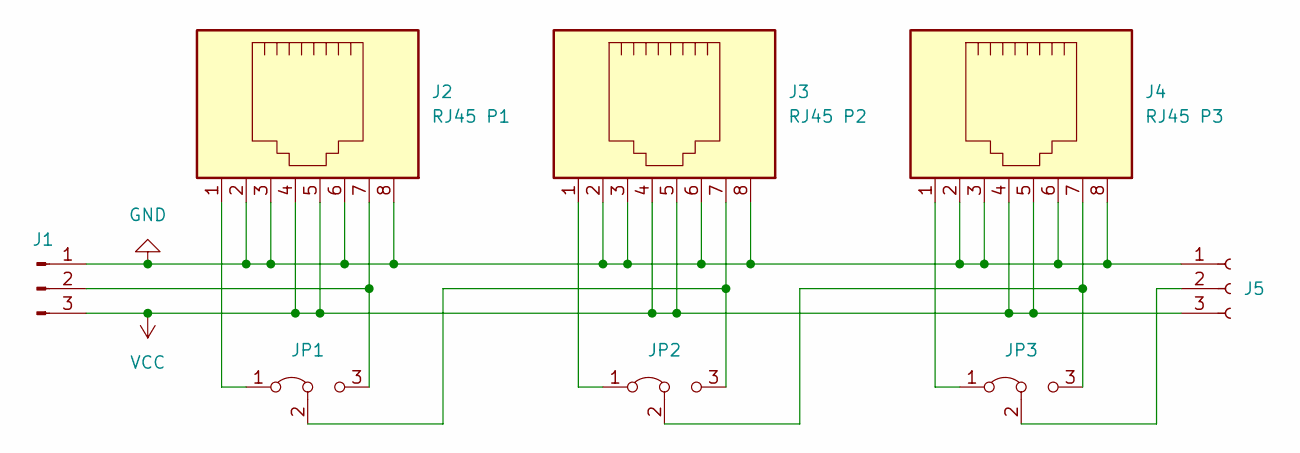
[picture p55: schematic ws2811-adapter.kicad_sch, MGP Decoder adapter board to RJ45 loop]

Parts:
J1: Conn_01x03_Pin; PinHeader_1x03_P2.54mm_Vertical
J2: RJ45 P1; RJ45_Amphenol_54602-x08_Horizontal
J3: RJ45 P2; RJ45_Amphenol_54602-x08_Horizontal
J4: RJ45 P3; RJ45_Amphenol_54602-x08_Horizontal
J5: Conn_01x03_Socket; PinSocket_1x03_P2.54mm_Vertical
JP1, JP2, JP3: Jumper_3_Bridged12; PinHeader_1x03_P2.54mm_Vertical

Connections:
GND: J1.1, J2.2, J2.3, J2.6, J2.8, J3.2, J3.3, J3.6, J3.8, J4.2, J4.3, J4.6, J4.8, J5.1
unnamed: J1.2, J2.7, JP1.3 (B)
unnamed: J5.2, JP3.2 (C)
unnamed: J2.1, JP1.1 (A)
unnamed: J3.7, JP1.2 (C), JP2.3 (B)
unnamed: J3.1, JP2.1 (A)
unnamed: J4.7, JP2.2 (C), JP3.3 (B)
unnamed: J4.1, JP3.1 (A)
VCC: J1.3, J2.4, J2.5, J3.4, J3.5, J4.4, J4.5, J5.3

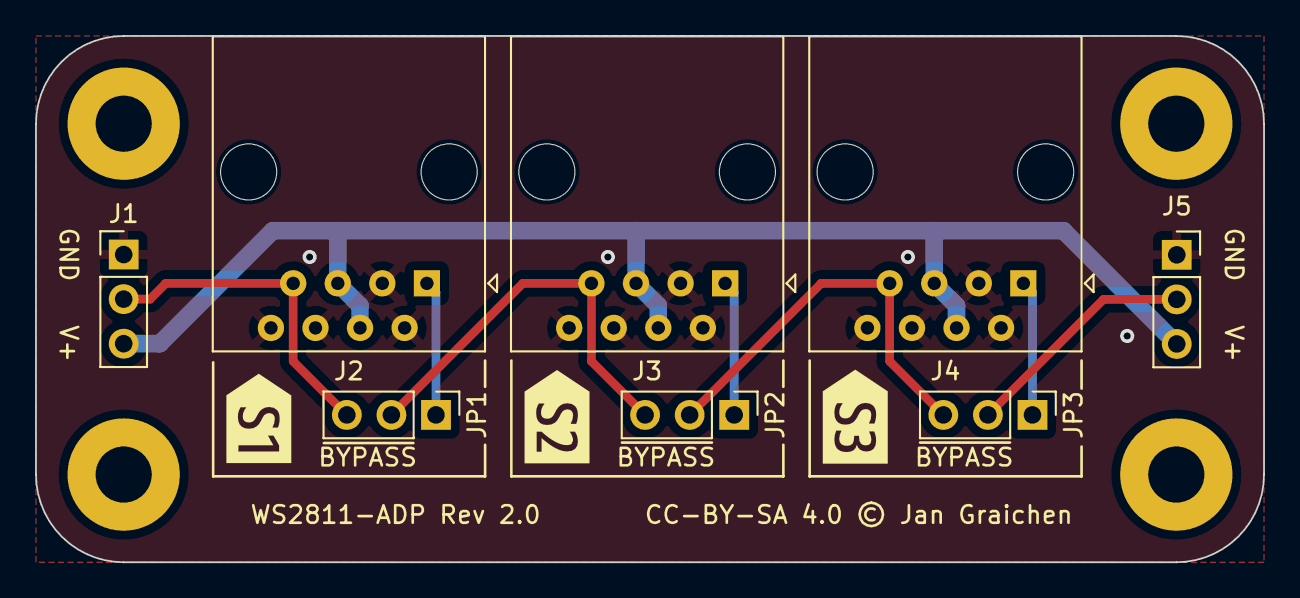
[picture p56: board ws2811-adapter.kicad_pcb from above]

Board: 2 copper layers, 70.0 x 30.0 mm, 11 parts (0 on the bottom side), 9 nets.

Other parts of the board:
kibuzzard-6563BF6D: G***; kibuzzard-6563BF6D
kibuzzard-6563BF62: G***; kibuzzard-6563BF62
kibuzzard-6563BF69: G***; kibuzzard-6563BF69

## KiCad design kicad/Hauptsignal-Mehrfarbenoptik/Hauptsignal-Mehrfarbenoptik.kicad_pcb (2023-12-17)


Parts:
D1, D7, D10: LED_W; LED_0402_1005Metric
D2: LED_ARGB; LRTBR48GP9Q71R7S526NP68
D6, D8, D9: LED_Y; LED_0402_1005Metric
J0: VCC; SolderWirePad_1x01_SMD_1x2mm
J1: VkzBw; SolderWirePad_1x01_SMD_1x2mm
J2: ARGB_2; SolderWirePad_1x01_SMD_1x2mm
J3: ARGB_3; SolderWirePad_1x01_SMD_1x2mm
J4: ARGB_4; SolderWirePad_1x01_SMD_1x2mm
J5: Zs7-3; SolderWirePad_1x01_SMD_1x2mm
J6: Ra; SolderWirePad_1x01_SMD_1x2mm
J7: Zs7-1; SolderWirePad_1x01_SMD_1x2mm
J8: Zs7-2; SolderWirePad_1x01_SMD_1x2mm
J9: Ra/Zs1; SolderWirePad_1x01_SMD_1x2mm

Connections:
unnamed: D1.1 (K), J1.1
unnamed: D1.2 (A), D2.1 (A), D6.2 (A), D7.2 (A), D8.2 (A), D9.2 (A), D10.2 (A), J0.1
unnamed: D2.2 (RK), J2.1
unnamed: D2.3 (GK), J3.1
unnamed: D2.4 (BK), J4.1
unnamed: D6.1 (K), J5.1
unnamed: D7.1 (K), J6.1
unnamed: D8.1 (K), J7.1
unnamed: D9.1 (K), J8.1
unnamed: D10.1 (K), J9.1



Board: 2 copper layers, 6.6 x 13.6 mm, 17 parts (10 on the bottom side), 10 nets.

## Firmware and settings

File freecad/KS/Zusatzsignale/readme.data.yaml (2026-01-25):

---
licht:
  ZS_Zs2_P:
    files:
      - ZS_Zs2_P
      - ZS_Zs2_P_NR
    notes:
      - Richtung "P"

  ZS_Zs3_2:
    files:
      - ZS_Zs3_2
      - ZS_Zs3_2_NR
    notes:
      - 20 km/h

  ZS_Zs3_3:
    files:
      - ZS_Zs3_3
      - ZS_Zs3_3_NR
    notes:
      - 30 km/h

  ZS_Zs3_4:
    files:
      - ZS_Zs3_4
      - ZS_Zs3_4_NR
    notes:
      - 40 km/h

  ZS_Zs6:
    files:
      - ~
      - ZS_Zs6_NR
    notes:
      - Gegengleisanzeiger

fest:
  default:
    columns: 1
    width: 410
    images: ["export/{name}-front.png", "export/{name}-axo.png"]

  ZS_Zs3_Fest:
    notes:
      - Zs3

  ZS_Zs3v_Fest:
    notes:
      - Zs3v

  ZS_Zs6_Fest_NR:
    notes:
      - Gegengleisanzeiger

aux:
  default:
    columns: 1
    width: 410
    images: ["export/{name}-front.png", "export/{name}-axo.png"]

  ZS_Halterung:
    - Halterung für Zusatzsignale am Mast

  ZS_Diffusor_96um:
    - Diffusor für Lichtzusatzsignale
    - 96µm (empfohlen)

  ZS_Diffusor_72um:
    - Diffusor für Lichtzusatzsignale
    - 72µm

  ZS_Diffusor_48um:
    - Diffusor für Lichtzusatzsignale
    - 48µm

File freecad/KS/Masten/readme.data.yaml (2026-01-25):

---
gittermasten:
  default:
    columns: 1
    width: 410
    images: ["export/{name}-front.png", "export/{name}-axo.png"]

  Gittermast_60_1ZS:
    - Ein Zusatzsignal

  Gittermast_60_2ZS:
    - Zwei Zusatzsignale

auslegermasten:
  default:
    columns: 1
    width: 410
    images: ["export/{name}-front.png", "export/{name}-axo.png"]

  Auslegermast_48_40R_1ZS:
    - 40er Ausleger
    - Rechts vom Gleis
  Auslegermast_48_40L_1ZS:
    - 40er Ausleger
    - Links vom Gleis

mastschilder:
  default:
    columns: 1
    width: 410
    images: ["export/{name}-front.png", "export/{name}-axo.png"]

  Mastschild_16_MS:
  Mastschild_16_VS:
  Mastschild_26_MS:
  Mastschild_26_VS:

aux:
  default:
    columns: 1
    width: 410
    images: ["export/{name}-front.png", "export/{name}-axo.png"]

  Mast_Korb_1:
  Mast_Auslegerkorb_40:
    - 40er Auslegerkorb
  Mast_Auslegerkorb_80:
    - 80er Auslegerkorb
  Leiter_16:
  Leiter_16_0504:
  Leiter_26:
  Leiter_26_0504:
  Technik_1:
  Sockel:

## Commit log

2022-11-12 Füge Pfeiler hinzu
    Signal Pfeiler
    Parametrisiert: Höhe, Länge der Stütze, Höhe des Seitenteils
    [Pfeiler.FCStd, Spreadsheet_Master.FCStd]
2022-11-12 Add PCB for Zs with 2 LEDs
    [panel.kicad_pcb, panel2.kicad_pcb, zusatzsignal.kicad_pcb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]
2022-11-13 Add PCB for main signals
    The PCB supports main signals and multi block signals. Unnecessary LEDs
    do not need to be populated. A green LED can be placed in the middle for
    main signals, and left for multi block signals.
    Other LED footprints support Zs1, Zs7, Sh1, Kennlicht, and the shortened
    breaking distance indicator.
    [signalschirm.kicad_pcb, signalschirm.kicad_sch]
2022-11-13 Shrink PCB element size and add rounded tracks and teardrops
    [signalschirm.kicad_pcb]
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2022-12-19 feat: Add untested multi-color signal front
    [Hauptsignal-Mehrfarbenoptik.kicad_pcb, Hauptsignal-Mehrfarbenoptik.kicad_sch]
2022-12-19 fix: Remove useless wire trace left from MSv2
    [Hauptsignal.kicad_pcb]
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2022-12-20 fix: MSO missing trace
    [Hauptsignal-Mehrfarbenoptik.kicad_pcb]
2022-12-20 MS: try using JLCPCB parts from library
    Assign some LEDs available in JLCPCB's inhouse catalog.
    [Mehrabschnittssignal.kicad_pcb, Mehrabschnittssignal.kicad_sch]
2023-01-15 MS: keep more space to border for breakout
    [Mehrabschnittssignal.kicad_pcb]
2023-10-31 feat: Change ZS to use 0403 LED
    Try production step with same LEDs as used on the main signals.
    [Zusatzsignal.kicad_pcb]
2023-10-31 feat: Update all panel code
    Generate panels with full local config for reproducability into a
    sub-directory, for example:
    kikit panelize -p panel.json Mehrabschnittssignal.kicad_pcb panel/MSv2-panel.kicad_pcb
    [Hauptsignal.kicad_pcb, Mehrabschnittssignal.kicad_pcb]
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2023-11-06 fix: ZS PCBs are to small for JLCPCB panelization
    JLCPCB only produces panelized boards with a minimum board size of
    5x5mm. Therefore, we must generate a mousebite "panel" and order that as
    "not-a-panel".
2023-11-18 Update LCSC part numbers in schema
    [Mehrabschnittssignal.kicad_pcb, Mehrabschnittssignal.kicad_sch]
2023-12-09 feat: Add signal mount LED driver boards
    [ws2811-adapter.kicad_pcb, ws2811-adapter.kicad_sch, ws2811-driver-12.kicad_pcb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]
2023-12-09 feat: Add 3D printables for signal mounts
    [M3-mount.FCStd, watti-assembly.FCStd, watti-assembly.step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]
2023-12-10 fix: LED ids
2023-12-14 Configure solder mask and silkscreen color
    Configure the default colors in board configuration for the current white finish.
    [ws2811-adapter.kicad_pcb, ws2811-driver-12.kicad_pcb, ws2811-driver-24.kicad_pcb]
2023-12-17 Add CC-BY-SA 4.0 license
    [Hauptsignal-Mehrfarbenoptik.kicad_pcb, Hauptsignal-Mehrfarbenoptik.kicad_sch, Hauptsignal.kicad_pcb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]
2023-12-22 feat: Rework WS2811 boards (Rev 2.0)
    * Change RJ45 pinout: The data signal is always paired with a ground
    line to increase signal stability, and the changed wireing eases the
    traces on the boards.
    * All WS2811 driver boards have a three pin header for direct drive now.
    They can be directly connected to a signal decoder, e.g. for testing.
    * The adapter boards has jumper pins to bypass RJ45 jacks, in case you
    want to connect another board using the final pin header.
    * Change pin header component to a better available JCSC parts number.
    * Move RJ45 jacks on driver boards a bit more off the board, so that
    there is less space between the jack and the outer side of the Watti
    carrie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
    [watti-w-latch-assembly.FCStd, watti-w-latch-assembly.step, ws2811-adapter.kicad_pcb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]
2024-01-01 extra: Add schema PDFs for MGP adapter boards
    [watti-w-latch-assembly.FCStd, ws2811-adapter.kicad_sch, ws2811-driver-12.kicad_sch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]
2024-01-13 feat: Add cover plate for Watti
    For now, only for the Watti with latch assembly.
    [watti-assembly.step, watti-assembly.stl, watti-body-w-latch.FCStd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]
2024-01-13 feat(VS): Add pre-signal repeater light
    [Vorsignal.kicad_pcb, Vorsignal.kicad_sch]
2024-01-23 feat: Add driver boards for KS Ls groups
    Two board variants for connecting one or two German light shunting signals
    via 2x3P 1mm pitch connectors.
    [ws2811-driver-6ls.kicad_pcb, ws2811-driver-6ls.kicad_sch, ws2811-driver-9ls.kicad_pcb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]
2024-01-25 feat(models): Add MS and VS signal screens
    [HS_Schirm_Blindstopfen_10.FCStd, HS_Schirm_Blindstopfen_15.FCStd, HS_Schirm_mit_Zs.FCStd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]
2024-01-25 feat(model): Erste Zusatzsignale Zs3/Zs3v 40 und Zs6
    [ZS_Nummer.FCStd, ZS_Signal.FCStd, ZS_Tafel_4.FCStd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]
2024-01-26 feat: Reorganize exports and add STEP export
    [MS_Sh1.step, MS_Sh1.stl, MS_Sh1_vkBw.step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]
2024-01-26 feat: Add Makefile and schema export to boards
    [ws2811-driver-12.step, ws2811-driver-24.step]
2024-01-26 feat: Start working on signal posts
    [Mast_Korb_1.FCStd, Mast_Korb_1.step, Mast_Korb_1.stl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]
2024-01-26 feat: Auslegermast 60/40 1ZS
    [Ausleger_40.FCStd, Auslegermast_1ZS.FCStd, Auslegermast_1ZS.step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]
2024-01-26 fix: Combined parts should not have mounting holes
    [Ausleger_Mast_42.FCStd, Ausleger_Signalmast_1ZS.FCStd, Auslegermast_1ZS.FCStd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]
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2024-01-27 feat: Optimize KS signal poles
    1. Remove mounts for signal pole sign. Instead, the same mounting holes
    as for the ladder are on both sides. I'll add a 3D printable pole
    sign mount next. This makes to the pole symmetrical too, so it can be
    used for left and right positions, if printed without the top pole
    segment.
    2. Add position pins for printing the signal pole in two or three
    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
    [Ausleger_40.FCStd, Ausleger_40.step, Ausleger_40.stl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]
2024-01-28 feat!: Do not export step by default anymore
    [Ausleger_40.step, Ausleger_Mast_42.step, Auslegermast_1ZS.step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]
2024-01-28 feat: Add new 40/60/80 beam poles, pole signals
    * Also includes parts for either pre-print or post-print assembly.
    [Ausleger_40.FCStd, Ausleger_40.stl, Ausleger_60.FCStd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]
2024-01-28 feat: Build post-print assemply poles from shared parts too
    1. The signal posts for post-print assembly are using the same base
    model parts now as the pre-post assembly poles, and are available in
    all three sizes too.
    2. Fix the inner pole pocket to 2.6mm for mounting a 2.5mm brass pole
    for all signal poles now.
    [Ausleger_Mast_32.FCStd, Ausleger_Mast_32.stl, Ausleger_Mast_42.FCStd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]
2024-01-28 feat: Add signal pole ladders
    [Leiter_16.FCStd, Leiter_16.stl, Leiter_26.FCStd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]
2024-01-28 fix: Ausleger 2ZS
    [Ausleger_Signalmast_2ZS.FCStd, Ausleger_Signalmast_2ZS.stl, Part_Ausleger_Mast_32.FCStd]
2024-01-28 feat: Add yellow tech mushroom
    [Technik_1.FCStd, Technik_1.stl]
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2024-02-02 feat: diffusors for ZS
    [ZS_Diffusor_48um.FCStd, ZS_Diffusor_48um.stl, ZS_Diffusor_72um.FCStd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]
2024-02-04 feat: Add ZS mount
    [ZS_Halterung.FCStd, ZS_Halterung.stl]
2024-02-05 feat: Thicker ladders for easier printing
    [Leiter_16_0504.FCStd, Leiter_16_0504.stl, Leiter_26_0504.FCStd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]
2024-02-15 fix: Zs6 sizing
    [ZS_Zs6_Fest_NR.FCStd, ZS_Zs6_Fest_NR.stl]
2024-02-15 feat: Add Zs3v plate
    [ZS_Halterung.stl, ZS_Nummer.FCStd, ZS_Zs3v_Fest_NR.FCStd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]
2024-02-15 Fix: ZS fest
    [ZS_Zs3_Fest.FCStd, ZS_Zs3_Fest.stl, ZS_Zs3v_Fest_NR.FCStd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]
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2024-03-24 chore: Reorganize main signal models
    * Consistent naming
    * Generate README preview from available files
    * Export STEP files for higher precision exports
    [MS_Sh1.FCStd, MS_Sh1.stl, MS_Sh1__A.FCStd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]
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2024-03-24 chore: Generate missing step model exports
    [watti-assembly.step, watti-plate.step, watti-w-latch-assembly.step]
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2024-03-29 fix: links to LS boards in README
2024-05-24 WIP: Redesign masts for single component production
    [Auslegermast_60_40R_2ZS.FCStd, Auslegermast_60_40R_2ZS.step, Part_Ausleger_40.FCStd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]
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2024-05-24 feat: Prepare new mast generation
    Mast changes:
    1) All masts will be printable a single mast components,
    2) added edges and walls for pushing cables through the part,
    3) increased stability with lattice mast parts.
    Technical improvements:
    1) New mast assembly will use FreeCAD 0.22dev builtin assembly
    workbench, and
    2) parts will be combined using sketches as attachment points.
    Note: export.py does not work for new assenbly files. I'll have to find
    a new workaround there.
    [Ausleger_40.FCStd, Ausleger_40.step, Ausleger_40.stl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]
2024-05-25 fix: Restore original export.py script
    Note: this does not work for STEP export of new assemblies
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2025-05-12 fix(deps): update dependency mkdocs-material to ~=9.6.13
2025-11-17 fix(deps): update dependency mkdocs-material to ~=9.7.0
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2026-01-25 KS: Rework Gittermast for better stability
    [Gittermast_60_2ZS.FCStd, Gittermast_60_2ZS.step, Gittermast_60_2ZS.stl]
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2026-10-29 fix(deps): update dependency mkdocs-material to ~=9.8.0

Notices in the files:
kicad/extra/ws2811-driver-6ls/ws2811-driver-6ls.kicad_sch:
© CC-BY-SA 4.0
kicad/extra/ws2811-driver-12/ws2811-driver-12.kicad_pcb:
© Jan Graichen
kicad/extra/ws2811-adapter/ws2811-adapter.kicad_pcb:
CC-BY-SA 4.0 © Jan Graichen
